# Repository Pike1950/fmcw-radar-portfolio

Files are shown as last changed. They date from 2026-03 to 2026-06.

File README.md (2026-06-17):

# 24 GHz FMCW Radar Sensor

A personal engineering portfolio project: a short-range 24 GHz FMCW radar sensor spanning an RF front end, a mixed-signal I/Q baseband, and an FPGA digital backend. It began as a baseband redesign of a Texas Tech senior capstone (HOTRODS, Spring 2020) and has grown into a complete radar sensor design, carried out with the discipline of 4+ years of hardware validation at Texas Instruments.

## Project Overview

This project demonstrates RF integration, mixed-signal PCB design, digital hardware design, hardware verification, and system-level engineering, with first-principles documentation explaining every design decision. The completed work is a corrected, first-principles baseband design and its system design document; the active phase is scaling that foundation into a full 24 GHz radar sensor.

## The System

An FMCW (Frequency-Modulated Continuous Wave) radar transmits a frequency chirp, receives the reflection from a target, and mixes it with the current transmit frequency to produce a low-frequency beat signal. The beat frequency is proportional to range; the chirp-to-chirp phase gives Doppler velocity, and a complex (I/Q) baseband resolves the sign of that velocity (approaching versus receding).

The sensor is built around an integrated 24 GHz transceiver MMIC and is partitioned into two boards plus a downstream digital backend:

```
RF FRONT-END MODULE                       I/Q BASEBAND BOARD                    DIGITAL BACKEND
BGT24MTR11 (24 GHz, 1 TX / 1 RX)          per channel:                          range-Doppler FFT
 on-chip VCO, PA, LNA, I/Q mixers   I,Q   VGA -> anti-alias -> 18-bit SAR ADC    (FPGA / MCU) -> host
 TX/RX antennas, chirp ramp,        --->  I and Q sampled simultaneously
 first gain stage                  (zero  SPI control of the MMIC
                                     IF)
```

The two boards meet at a low-frequency analog I/Q interface, not a 24 GHz one, because the MMIC downconverts on-chip. That seam is what makes the split practical: the costly, iteration-prone 24 GHz RF and antennas stay on a small module, while the baseband stays on inexpensive FR4 and can be brought up and validated on its own.

## Evolution: Rev A to Rev B to Rev C

- **Rev A (2020).** 5.8 GHz, 3 RX channels, 182 components, Eagle, a single flat sheet. Built as the Texas Tech senior capstone; non-functional. The headline defect was a 10 kHz chirp rate that produced only about 5 ADC samples per ramp, far too few for FFT range extraction.
- **Rev B (current).** Began as a scaled, corrected 5.8 GHz baseband (one channel, KiCad 9, a modern signal chain, DFT-first methodology), captured as schematic plus a first-principles system design document. Rather than fabricate that band, Rev B is now redefined as the **24 GHz I/Q radar**: the band moves to 24 GHz, the project adopts the BGT24MTR11 (so it now owns the RF front end, not just the baseband), the baseband goes complex I/Q, and the sensor splits into an RF module and a baseband board. The baseband modernization below carries forward intact.
- **Rev C.** Additional receive channels for angle estimation, the original trilateration goal, on a proven single-channel Rev B.

### Baseband modernization (carried forward from the 5.8 GHz Rev B)

These corrections to the capstone baseband are band-agnostic and carry directly into the 24 GHz I/Q design.

| Aspect | Rev A (2020) | Rev B baseband (carried forward) |
| --- | --- | --- |
| EDA | Eagle 9.5, flat single sheet | KiCad 9, hierarchical |
| VGA | LT6230 + MCP4017 I²C digital pot | PGA113 (SPI, internal gain resistors) |
| ADC | ADS1174 (16-bit, 64-pin QFP, solder bridges) | ADS8881 (18-bit, 10-pin VSSOP) |
| SE to Diff | LTC6242 (improvised, no VOCM) | THS4531A (true FDA with VOCM) |
| Power | Single 3.3 V rail | 3V3A / 3V3D split via ferrite bead |
| Reference | Resistor divider | REF5025 (2.500 V, 0.05%, 3 µVpp) |
| DFT | None | J_DFT header, 17 TPs, 5 MMCX, 6 isolation resistors |

On top of this, the 24 GHz move adds an integrated-MMIC RF front end, a complex I/Q baseband (the chain above duplicated for I and Q with simultaneous sampling), and the two-board partition.

## Key Documents

| Document | Description |
| --- | --- |
| [System Design Document](https://pike1950.github.io/fmcw-radar-portfolio/docs/system-design/System_Design_Document_RevB.html) | The 24 GHz radar system SDD, restyled to the PMVB module-doc schema with PHYSICS / DECISION / TRADEOFF / RISK reasoning callouts. Covers the two-board architecture, the carry-over analog design (power, references, gain, anti-alias filter, DFT), the FMCW principles, and an open decision register tracking the remaining 24 GHz choices. |

## Technical Highlights

### Analog and mixed-signal design

- **Supply splitting via ferrite bead.** BLM18PG221SN1D (220 Ω at 100 MHz) isolates analog from digital supply noise on a single continuous ground plane, with first-principles impedance analysis.
- **Paired decoupling capacitors.** Matched cap pairs (for example 10 µF + 100 nF) with different self-resonant frequencies for low impedance across a wide band, placed per a derived trace-inductance budget.
- **DFT-first methodology.** Test points, MMCX probes, and isolation resistors designed before the signal chain, now applied per channel for I and Q.

### System-level analysis

- **Chirp-rate correction.** Identified the Rev A parameter mismatch (about 5 samples per ramp) and derived the corrected chirp plan from first principles (sample-count-per-ramp to FFT resolution). The analysis is carrier-independent and re-derives the 24 GHz filter and ADC plan.
- **Band move to 24 GHz with complex I/Q.** Moving from 5.8 GHz to the 24 GHz ISM band raises range resolution from about 5 m to about 0.6 m and brings the RF front end into scope through an integrated MMIC. Complex I/Q sampling adds sign-of-velocity discrimination.
- **Designed for validation.** The board is designed for standalone bring-up and characterization on a homebrew SCPI instrument platform (see Related Repositories).

### Digital backend (planned)

SystemVerilog modules targeting the Gowin GW5A (Tang Primer 25K): SPI masters for the ADS8881 and the MMIC, a chirp ramp / DDS generator, a configurable FIR, and a deterministic timing controller, all verified with self-checking Verilator testbenches. See `digital/spi-controller/`.

## Related Repositories

| Repository | Description | Status |
| --- | --- | --- |
| [32-bit RISC Pipelined Processor](https://github.com/Pike1950/BradW_ECE4375_RISC_Pipeline) | 4-stage pipelined CPU refactored from Verilog to SystemVerilog. Shares the Verilator-clean SystemVerilog methodology used for this radar's digital backend. | SV conversion complete, synthesis next |
| [Poor Man's Validation Bench](https://github.com/Pike1950/poor-mans-validation-bench) | Modular SCPI + MCP instrument platform: Raspberry Pi 5 orchestration, Pico 2W USB-TMC modules, tiered FPGA. The bring-up and characterization platform for this radar. | Phase 0 complete; Module 1E (AWG) in build |

## Tools and Technologies

- **EDA:** KiCad 9. RF module on a controlled high-frequency stackup; baseband on FR4.
- **Simulation:** LTspice (analog), Verilator (digital), GTKWave (waveforms).
- **HDL:** SystemVerilog (digital backend, verification).
- **FPGA target:** Gowin GW5A (Sipeed Tang Primer 25K) for the digital backend.
- **Documentation:** Markdown rendered to HTML via Pandoc, PMVB-schema design docs with first-principles reasoning callouts.
- **Test automation:** PyVISA, integrating with the Poor Man's Validation Bench.

## Background

This project is one of four interconnected portfolio tracks:

1. **FMCW Radar Sensor** (this repo). RF integration plus mixed-signal PCB plus digital, with first-principles documentation and DFT-first methodology.
2. **Hardware Validation.** 4+ years at Texas Instruments (gate-driver characterization, automated test with LabVIEW / TestStand / PXI, DUT board design in Altium).
3. **Digital Design.** A pipelined RISC processor in SystemVerilog.
4. **Test Infrastructure.** The Poor Man's Validation Bench, a SCPI + MCP instrument platform.

The radar connects all four: a mixed-signal and RF sensor (track 1), designed with validation-engineer discipline (track 2), with an FPGA backend (track 3) characterized on the homebrew bench (track 4).

## Status

- **5.8 GHz baseband foundation (complete).** First-principles system design document and schematic capture of the corrected single-channel baseband. Established the methodology, the analog signal chain, and the DFT infrastructure that all carry forward.
- **24 GHz radar system design (in progress).**
  - System SDD reframed to the radar scope and the PMVB schema.
  - D1 resolved: BGT24MTR11 (1 TX / 1 RX), two-board partition (RF Front-End Module plus I/Q Baseband Board).
  - Open: antenna and RF stackup, ADC arrangement, ramp generation, chirp plan, and digital backend (tracked in the SDD decision register).
- **Next.** RF Front-End Module and I/Q Baseband Board schematics; digital backend RTL; bring-up and characterization on the Poor Man's Validation Bench.

## License

A personal engineering portfolio project. The FMCW radar originated as a Texas Tech senior capstone (HOTRODS, Spring 2020). The Rev B redesign, the 24 GHz radar system design, documentation, and all digital design work are by Bradley Ward.

## Contact

Bradley Ward, bradw858@gmail.com, [LinkedIn](https://linkedin.com/in/bradley-ward-49087766/)

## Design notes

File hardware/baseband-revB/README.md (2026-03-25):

# Baseband Rev B — KiCad 9 Schematic

## Overview

Single-channel FMCW radar baseband signal conditioning path. 4-sheet hierarchical schematic, 90 components, 0 ERC errors.

## Sheets

| Sheet | File | Function | Components |
|---|---|---|---|
| Root | `Baseband PCB.kicad_sch` | Top-level hierarchy with sheet instances | — |
| A | `Baseband_Power_Refs.kicad_sch` | Power (TPS7A2033 LDO, 3V3A/3V3D split), References (REF5025, OPA320 VCM buffer) | 29 |
| B | `Baseband_IF_Input_Protection_Bias.kicad_sch` | SMA input, ESD protection (TPD1E10B06), AC coupling, DC bias to VCM | 7 |
| C | `Baseband_PGA_AntiAlias.kicad_sch` | PGA113 (1–200× gain), 4th-order Sallen-Key Butterworth LP at 15 kHz (LTC6242) | 19 |
| D | `Baseband_FDA_Driver_ADC_SPI_Interface.kicad_sch` | THS4531A FDA, ADS8881 18-bit SAR ADC, J_DFT header, SPI interface | 35 |

## Key Design Decisions

See [Design Rationale](../../docs/design-rationale/RevB_Design_Rationale.html) for first-principles analysis of every component choice.

## Status

- [x] Schematic complete
- [x] ERC clean (0 errors, 0 warnings)
- [ ] Layout in progress

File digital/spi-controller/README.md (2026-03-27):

# SPI Controller — SystemVerilog

## Overview

A SystemVerilog SPI master controller designed to interface with the FMCW radar baseband's ADS8881 ADC and PGA113 programmable gain amplifier. This module bridges the analog baseband project with the digital verification track, demonstrating the full V-model from specification through bench validation.

## Status

**Planned** — RTL design and verification are Phase 4 of the project roadmap.

## Target Specifications

### ADS8881 SPI Interface
- CPOL=0, CPHA=1 (SPI Mode 1)
- SCLK: up to 70 MHz
- 18-bit data, MSB first
- CONVST pulse initiates conversion (600 ns conversion time)
- Data clocked out on SCLK falling edge

### PGA113 SPI Interface
- CPOL=0, CPHA=0 (SPI Mode 0)
- 16-bit command word (8-bit register address + 8-bit gain code)
- Separate chip select from ADC

## Planned Architecture

```
                    SPI Controller (Top)
    ┌─────────────────────────────────────────────┐
    │  ┌────────────┐     ┌────────────┐          │
    │  │ ADC SPI    │     │ PGA SPI    │          │
    │  │ Master     │     │ Master     │          │
    │  │ (Mode 1)   │     │ (Mode 0)   │          │
    │  └──────┬─────┘     └──────┬─────┘          │
    │         │                  │                 │
    │  ┌──────▼──────────────────▼─────┐          │
    │  │        Timing Controller      │          │
    │  │  (CONVST generation, gain     │          │
    │  │   scheduling, sample clock)   │          │
    │  └───────────────────────────────┘          │
    │                                             │
    │  ┌───────────────────────────────┐          │
    │  │     Data Output Interface     │──→ UART  │
    │  │  (FIFO, framing, streaming)   │          │
    │  └───────────────────────────────┘          │
    └─────────────────────────────────────────────┘
```

## Verification Plan

- Constrained-random testbench with self-checking scoreboard
- Timing verification against ADS8881 datasheet specifications
- PGA gain code verification against PGA113 register map
- Coverage targets: all gain settings, all timing corner cases

## FPGA Targets

- **Gowin GW5A** (Sipeed Tang Primer 25K, ~$35, in hand) — 23,040 LUT4, 1008Kb BSRAM, 3 PMOD ports. Primary target for the radar digital backend. Gowin EDA + open-source Yosys/Apicula toolchain.
- **Gowin GW5AST-138** (Sipeed Tang Mega 138K Pro, ~$200) — 138K LUT4, PCIe 3.0 x4, dual SFP+. Phase 2 target for expanded digital backend and high-speed interface work.

## Toolchain

- **Simulation:** Verilator + GTKWave (WSL2 or native Linux)
- **Synthesis:** Yosys (iCE40) or Gowin EDA (GW1NR-9)
- **Place & Route:** nextpnr (iCE40) or Gowin EDA

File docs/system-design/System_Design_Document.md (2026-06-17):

# 24 GHz FMCW Radar System Design Document

## Rev B: 24 GHz I/Q

**Version:** 0.8
**Project:** FMCW Radar Portfolio (`fmcw-radar-portfolio`)
**Revision:** Rev B (24 GHz I/Q)
**Status:** In Design
**Engineer:** Bradley Ward
**Scope:** A complete 24 GHz FMCW radar sensor, partitioned into two boards: an **RF Front-End Module** (BGT24MTR11, 24 GHz antennas, chirp ramp, first gain stage) and an **I/Q Baseband Board** (gain, anti-alias filtering, dual simultaneous-sampling ADC, digital interface). The digital backend that runs the range-Doppler FFT is downstream of both.

---

## Document Conventions

This document follows the PMVB module-doc section schema. The reasoning style from the original FMCW SDD is preserved: load-bearing design choices are called out with one of four tags so the "why" is explicit and auditable.

<div class="callout callout-blue"><strong><span class="tag tag-physics">PHYSICS</span> First-principles derivation or physical reasoning.</strong></div>
<div class="callout callout-teal"><strong><span class="tag tag-decision">DECISION</span> A specific design choice with its rationale.</strong></div>
<div class="callout"><strong><span class="tag tag-tradeoff">TRADEOFF</span> What was gained versus what was given up.</strong></div>
<div class="callout callout-red"><strong><span class="tag tag-risk">RISK</span> A known limitation or sensitivity requiring attention.</strong></div>

A fifth marker is specific to this revision. Because the 24 GHz design is mid-definition, blocks that depend on an unresolved decision are flagged and cross-referenced to the decision register in section 10:

<div class="pending"><strong>PENDING (Dx):</strong> content blocked on an open decision; see section 10.</div>

Per the PMVB rule, the body describes what is used. Where a 24-GHz choice is not yet locked, the section states what carries over from the 5.8 GHz design, what must change, and which decision gates it, rather than guessing values that will move.

---

## Table of Contents

- [1. Theory of Operation](#theory-of-operation)
  - [1.1 What the system does](#what-the-system-does)
  - [1.2 Signal chain](#signal-chain)
  - [1.3 Methodology: work backward from the ADC](#methodology-work-backward-from-the-adc)
  - [1.4 The coupled parameter chain](#the-coupled-parameter-chain)
  - [1.5 The baseband is set by the chirp plan, not the carrier](#the-baseband-is-set-by-the-chirp-plan-not-the-carrier)
- [2. Functional Block Diagram](#functional-block-diagram)
- [3. Schematic Notes](#schematic-notes)
  - [3.0 RF Front-End Module](#rf-front-end-module)
  - [3.1 Sheet A: Power and References](#sheet-a-power-and-references)
  - [3.2 Sheet B: I/Q Input from the MMIC](#sheet-b-iq-input-from-the-mmic)
  - [3.3 Sheet C: Gain and Anti-Alias Filter](#sheet-c-gain-and-anti-alias-filter)
  - [3.4 Sheet D: I/Q Digitization](#sheet-d-iq-digitization)
  - [3.5 DFT Infrastructure](#dft-infrastructure)
- [4. Pin Assignments](#pin-assignments)
- [5. Specifications](#specifications)
  - [5.1 Governing equations](#governing-equations)
  - [5.2 Key relationships, visualized](#key-relationships-visualized)
- [6. Sample Applications](#sample-applications)
- [7. Bill of Materials](#bill-of-materials)
- [8. Calibration Procedure](#calibration-procedure)
- [9. Layout Design Rationale](#layout-design-rationale)
- [10. Open Decisions and Known Issues](#open-decisions-and-known-issues)
- [11. References](#references)

---

## 1. Theory of Operation

### 1.1 What the system does

This is a complete short-range 24 GHz FMCW radar sensor. A transceiver MMIC transmits a frequency chirp, receives the reflection, and downconverts it on-chip to a complex baseband beat signal; the baseband then conditions and digitizes that signal into complex samples for a downstream range-Doppler FFT.

The sensor is partitioned into two boards (decision D1, section 10):

- **RF Front-End Module.** The Infineon BGT24MTR11 (1 TX / 1 RX) integrated transceiver, its 24 GHz TX and RX antennas, the chirp ramp source, and a first gain stage. The MMIC contains the VCO, PA, LNA, and quadrature mixers and presents differential in-phase (I) and quadrature (Q) beat signals at zero IF.
- **I/Q Baseband Board.** Per-channel gain and anti-alias filtering, simultaneous 18-bit sampling of I and Q, MMIC configuration over SPI, and the digital interface to the backend.

The two boards meet at a low-frequency analog I/Q interface, not a 24 GHz interface, because the MMIC has already downconverted on-chip. That is what makes the split practical (section 10, D1).

The radar is a signal-acquisition path, not a signal processor: it transforms microvolt-to-millivolt beat signals into clean complex samples, and range and velocity extraction happen downstream in the FFT engine.

<div class="callout callout-teal"><strong><span class="tag tag-decision">DECISION</span> 24 GHz integrated MMIC, two-board partition</strong>
<p>The 5.8 GHz Rev B was baseband-only and treated the RF front end (a discrete free-running VCO, mixers, and LNA) as external. At 24 GHz the project adopts the BGT24MTR11, which collapses that discrete RF chain into a single MMIC, so the RF front end is now part of the design. The sensor is split into an RF Front-End Module and an I/Q Baseband Board because the inter-board seam is low-frequency analog I/Q: that keeps the costly 24 GHz material and the iteration-prone RF isolated to a small board while the baseband stays on cheap FR4 and can be validated standalone. The complex I/Q output is also what enables sign-of-velocity discrimination (sections 1.5 and 3.4).</p></div>

### 1.2 Signal chain

Locked blocks are in plain text; blocks whose implementation depends on an open decision are flagged.

```
RF FRONT-END MODULE
  24 GHz MMIC (on-chip VCO, PA, LNA, I/Q mixers); TX and RX via 24 GHz antennas
  I, Q (zero IF) -> first gain stage -> [ I/Q interface connector ]
  chirp ramp -> MMIC VCO tune (kept local to this board)     (DAC ramp, calibrated)

I/Q BASEBAND BOARD
  [ I/Q interface connector ] -> per channel: VGA -> anti-alias filter -> SAR ADC
     I and Q sampled simultaneously to preserve complex phase
  -> digital backend: Tang Primer 25K FPGA (range-Doppler FFT) -> host
  MMIC configuration + control over SPI (routed across the connector)
```

The two conditioning chains (I and Q) are nominally identical. Channel-to-channel gain and phase match is a first-class concern: I/Q imbalance maps directly to image-frequency leakage in the complex spectrum and corrupts the sign of the measured velocity.

### 1.3 Methodology: work backward from the ADC

This methodology carries over from the 5.8 GHz design unchanged, because it is independent of carrier frequency and of real-versus-complex sampling. Every analog decision is anchored to what the ADC needs to see.

<div class="callout callout-blue"><strong><span class="tag tag-physics">PHYSICS</span> The ADC defines the budget</strong>
<p>The ADS8881 digitizes a differential input against a 2.500 V reference (REF5025). One LSB at 18 bits over the differential full scale is V<sub>REF</sub> &times; 2 / 2<sup>18</sup> = 5.000 V / 262,144 &approx; 19 &micro;V. Every upstream stage exists to deliver a clean signal into that window: the VGA fills the ADC range regardless of target distance, the anti-alias filter keeps out-of-band energy from folding in, and the reference and bias networks must hold stable to a small fraction of an LSB or they waste resolution. Noise or offset referred to the input is only meaningful relative to that ~19 &micro;V step.</p></div>

### 1.4 The coupled parameter chain

The chirp timing, the sample rate, and the FFT size are not independent. They are bound by one relation that Rev A violated and Rev B respects.

<div class="callout callout-blue"><strong><span class="tag tag-physics">PHYSICS</span> The three coupled parameters</strong>
<p>f<sub>s</sub> &times; T<sub>sweep</sub> = N<sub>samples</sub>, and N<sub>samples</sub> must be at least N<sub>FFT</sub> for useful frequency resolution.</p>
<p>Rev A set T<sub>sweep</sub> = 50 &micro;s without checking: at 100 kS/s that is only 5 samples per ramp, and a 5-point FFT has no resolution. The corrected design sets T<sub>sweep</sub> in the millisecond range so that f<sub>s</sub> &times; T<sub>sweep</sub> yields several hundred samples per ramp, enough for a 512-point FFT. The ADC sample rate did not cause the Rev A failure; the chirp rate did.</p></div>

<div class="callout callout-teal"><strong><span class="tag tag-decision">DECISION</span> Chirp plan (D6)</strong>
<p>Sweep 250 MHz over a 1 ms chirp (slope 250 GHz/s), 50 m design range, sampled at 256 kSPS for 256 samples per chirp and a 256-point range FFT (~83 range bins of 0.6 m). 128 chirps per frame give a 128 ms frame (~8 frames/s), ~5 cm/s velocity resolution, and ±3.1 m/s unambiguous velocity. The max beat at 50 m is 83 kHz, well inside the 128 kHz Nyquist, leaving the anti-alias filter an 83-to-128 kHz transition band. More range is paid for with sample rate (the ADS8881 reaches 1 MSPS), not chirp time, so velocity is unaffected.</p></div>

### 1.5 The baseband is set by the chirp plan, not the carrier

This is the point that makes the band move tractable: moving from 5.8 GHz to 24 GHz does not, by itself, change the baseband.

<div class="callout callout-blue"><strong><span class="tag tag-physics">PHYSICS</span> Beat frequency depends on slope and range, not carrier</strong>
<p>For a target at range R, the beat frequency is f<sub>beat</sub> = 2&middot;R&middot;S / c, where S is the chirp slope (sweep bandwidth / sweep time). The carrier frequency f<sub>0</sub> does not appear. So the anti-alias filter cutoff and the ADC rate are governed by the maximum range beat, set by the chirp plan, and are re-derived with the same analysis used at 5.8 GHz.</p>
<p>Range resolution is set by usable sweep bandwidth: &Delta;R = c / (2B). Across the 24 GHz ISM band (~250 MHz usable) the floor is about 0.6 m, roughly an 8&times; improvement over the 30 MHz / 5.0 m of the 5.8 GHz §15.245 mode, and a hard limit independent of the ADC.</p></div>

<div class="callout callout-blue"><strong><span class="tag tag-physics">PHYSICS</span> What the carrier does change: Doppler</strong>
<p>Doppler shift scales with carrier: f<sub>D</sub> = 2&middot;v&middot;f<sub>0</sub> / c. At 24 GHz the Doppler is about 4&times; that at 5.8 GHz for the same velocity. Doppler is resolved in the slow-time (chirp-to-chirp) FFT and sets velocity-axis scaling and maximum unambiguous velocity; it does not drive the fast-time anti-alias filter, which remains governed by the range beat.</p></div>

<div class="callout callout-teal"><strong><span class="tag tag-decision">DECISION</span> Complex I/Q resolves the sign of velocity</strong>
<p>A single real beat channel cannot tell an approaching target from a receding one; both fold to the same positive beat frequency. Sampling I and Q gives a complex baseband whose FFT is two-sided, so positive and negative Doppler are distinct. This is the architectural reason the board doubles to two channels (section 3.4) and the reason simultaneous sampling and I/Q match matter.</p></div>

---

## 2. Functional Block Diagram

The system and sheet-level block diagrams live in `docs/block-diagrams/` (`block_diagram_system.svg`, `block_diagram_sheet_a.svg`, `block_diagram_sheets_bcd.svg`).

The existing diagrams show the 5.8 GHz single real chain (one mixer input, one PGA, one filter, one FDA, one ADC). They are redrawn to show the two-board partition: the BGT24MTR11 with its antennas and first gain stage on the RF Front-End Module, the differential I and Q crossing the interface connector, and the two parallel conditioning chains into a simultaneous-sampling ADC stage on the I/Q Baseband Board.

---

## 3. Schematic Notes

The design spans two boards. The notes below explain the intent behind each block; the full schematics live in the KiCad projects, and detailed per-board design documents (RF Front-End Module, I/Q Baseband Board) will sit under this system SDD as each board matures, mirroring the PMVB per-module docs. Section 3.0 summarizes the RF Front-End Module; sections 3.1 to 3.5 cover the I/Q Baseband Board, where Sheet A (power and references) and the DFT infrastructure carry over from the 5.8 GHz design and Sheets B, C, and D are reworked for the MMIC I/Q interface and the dual-channel architecture.

### 3.0 RF Front-End Module

The RF Front-End Module carries the BGT24MTR11 transceiver, its 24 GHz TX and RX antennas, the chirp ramp source, a first gain stage on each of the I and Q outputs, and the connector to the baseband board.

<div class="callout callout-teal"><strong><span class="tag tag-decision">DECISION</span> The first gain stage lives on the RF module</strong>
<p>The I and Q signals leaving the MMIC are low-level (microvolt to millivolt) and have to cross a board-to-board connector. A first gain stage on the RF module amplifies them before the crossing, so the inter-board interface carries a larger, lower-impedance signal and is far less vulnerable to pickup. The remaining gain and all of the filtering live on the baseband board.</p></div>

<div class="callout callout-teal"><strong><span class="tag tag-decision">DECISION</span> External patch array on 4-layer RO4350B (D2)</strong>
<p>The RF module uses external PCB patch antennas (a small patch array), microstrip-fed from the BGT24MTR11, plus a build-option 2.92 mm connector launch (DNP) so an external 24 GHz antenna can drive first bring-up. The stackup is 4-layer RO4350B (L1 RF and antenna, L2 solid ground reference, L3 power, L4 control), fabricated at PCBWay, which runs 4-layer Rogers. RO4350B sits just above its sweet spot at 24 GHz, giving up a little patch efficiency versus RO3003, which is held as a later upgrade. ENIG finish for the fine-pitch MMIC and the patches.</p></div>

<div class="callout callout-teal"><strong><span class="tag tag-decision">DECISION</span> DAC-driven chirp ramp with calibration (D5)</strong>
<p>The VCO tune voltage is generated open-loop by a DAC and pre-distorted from a measured frequency-versus-voltage curve, rather than closed-loop with an FMCW ramp PLL. Over the ~250 MHz sweep at 24 GHz the fractional bandwidth is about 1%, the same regime in which the original 5.8 GHz design ran its VCO, so the residual nonlinearity is modest and a calibrated open-loop ramp is adequate. The ramp source stays local to the RF module so the tune line is short. The accepted cost is open-loop drift with temperature and the calibration table to maintain; an ADF4159-class ramp PLL is the upgrade path if bench measurement shows linearity is limiting range accuracy.</p></div>

### 3.1 Sheet A: Power and References

Sheet A is band-agnostic and carries over essentially intact, with one change: the common-mode and reference nets now fan out to two channels instead of one. The architecture is a single 5 V input, an on-board 3.3 V LDO, an analog/digital supply split via ferrite bead, a precision 2.500 V reference, and a buffered mid-supply common-mode rail.

<div class="callout callout-teal"><strong><span class="tag tag-decision">DECISION</span> Analog/digital split via ferrite bead, single ground plane</strong>
<p>The 3V3A and 3V3D rails are separated by a BLM18PG221SN1D ferrite bead (220 &Omega; at 100 MHz, under 1 &Omega; DC). It passes DC cleanly to the analog rail while presenting high impedance to the digital switching spectrum, giving over 40 dB of attenuation to SPI-edge noise. The ground stays a single continuous plane; isolation is done on the supply, not by splitting the return (see section 9.3).</p></div>

<div class="callout callout-blue"><strong><span class="tag tag-physics">PHYSICS</span> Why V<sub>CM</sub> = V<sub>DD</sub>/2 = 1.650 V</strong>
<p>All active parts run from a single 3.3 V supply with no negative rail, so an AC signal must be biased to the midpoint to maximize swing before clipping. At V<sub>CM</sub> = 1.650 V the signal gets symmetric &plusmn;1.65 V headroom (less op-amp saturation, ~100&ndash;200 mV per rail). This common-mode voltage appears everywhere: it biases the I/Q inputs, sets the PGA reference, and drives each FDA's VOCM pin. A single buffered, low-impedance source (an OPA320 on Sheet A) feeds all stages so they share one common mode; any mismatch becomes a DC offset that wastes ADC range. With two channels, the same buffered V<sub>CM</sub> and V<sub>REF</sub> nets fan out to both I and Q.</p></div>

<div class="callout callout-blue"><strong><span class="tag tag-physics">PHYSICS</span> Reference error is gain error</strong>
<p>REF5025 (2.500 V, 0.05%, 3 &micro;V<sub>pp</sub> noise) sets the ADC full scale. Any error in V<sub>REF</sub> maps directly to a gain error on every reading: gain error = &Delta;V<sub>REF</sub> / V<sub>REF,nom</sub>. The reference therefore gets a paired-capacitor decoupling network (10 &micro;F bulk + 100 nF high-frequency, different self-resonant frequencies) at the ADC reference pin, as the ADS8881 datasheet recommends.</p></div>

<div class="callout callout-teal"><strong><span class="tag tag-decision">DECISION</span> Decoupling placement is a derived budget, not a guideline</strong>
<p>Trace inductance is ~1 nH/mm. The placement distance for each bypass capacitor follows from the frequency it must serve and the acceptable trace impedance: the higher the frequency, the shorter the trace. The design's rules (100 nF within 2 mm, 1 &micro;F within 5 mm, 10 &micro;F within 10 mm) are the quantitative result of that inductance-versus-impedance analysis, not copied from a reference design. This carries over unchanged.</p></div>

### 3.2 Sheet B: I/Q Input from the MMIC

This is the most-changed sheet. The 5.8 GHz Sheet B was a single-ended, AC-coupled input: an SMA from a discrete mixer, a series current-limit resistor, an ESD diode, a 100 nF C0G capacitor to strip the mixer's undefined DC, and a 47 kΩ bias to V<sub>CM</sub> (high-pass corner ~34 Hz). For a 24 GHz zero-IF I/Q front end that topology is largely replaced.

<div class="pending"><strong>Input interface (D1 resolved):</strong> The BGT24MTR11 presents differential I and Q at zero IF. The baseband-board input interfaces to two differential pairs arriving over the interconnect from the RF module's first gain stage, not a single-ended SMA. The exact termination, common-mode handling, and ESD network follow the BGT24MTR11 I/Q output specification.</div>

<div class="callout callout-red"><strong><span class="tag tag-risk">RISK</span> Zero-IF DC must not be blocked</strong>
<p>The old Sheet B AC-coupled specifically to remove the mixer's undefined DC bias. At zero IF the beat band extends down to DC, so a stationary or slow-moving target sits near DC. The Rev B input cannot high-pass the way the 5.8 GHz design did. DC offset is handled instead (per-channel calibration or a servo), and 1/f (flicker) noise now sits in-band and must be budgeted. This is the single biggest conceptual change from the old input stage.</p></div>

<div class="callout callout-teal"><strong><span class="tag tag-decision">DECISION</span> Keep ESD and current-limiting, adapted to differential</strong>
<p>The connector/interface ESD protection (TPD1E10B06 class) and the per-line series current-limit concept carry over, applied to each leg of the differential I and Q pairs rather than a single-ended line.</p></div>

### 3.3 Sheet C: Gain and Anti-Alias Filter

The gain and filter method carries over; the component values re-derive from the 24 GHz chirp plan (D6), and the whole chain duplicates for I and Q.

<div class="callout callout-blue"><strong><span class="tag tag-physics">PHYSICS</span> Variable gain follows the R<sup>&minus;4</sup> range law</strong>
<p>Received power varies as R<sup>&minus;4</sup> (the radar range equation): a target at 10 m returns 10,000&times; the power of the same target at 100 m, about 40 dB, and a 100-to-1 span is roughly 80 dB, which approaches the ~84 dB an 18-bit SAR can usefully cover and is exceeded for wider spans. Without variable gain the ADC would clip on near targets or bury far ones in the noise. An SPI-controlled differential VGA per channel fills the ADC window for each range regime. (The Rev B PGA113 was a single-ended part; the differential I/Q here keeps the gain stage differential, so the adaptive-gain concept and the SPI control carry forward, but the part changes.)</p></div>

<div class="callout callout-teal"><strong><span class="tag tag-decision">DECISION</span> Anti-alias before sampling, cutoff set by Nyquist not by the chirp</strong>
<p>A 4th-order Sallen-Key Butterworth low-pass sits before each ADC. Its cutoff is set by f<sub>s</sub>/2 and the signal band, not by the chirp rate. Whether the chirp is fast or slow, energy above Nyquist must be kept from folding into the band. The topology and the singly-terminated design method carry over from the 5.8 GHz Sheet C. With the chirp plan set (D6: 256 kSPS, 83 kHz max beat), the cutoff lands near 100 kHz, inside the 83-to-128 kHz window between the max beat and Nyquist; the L/C/R values follow from a Butterworth synthesis at that cutoff.</p></div>

<div class="callout"><strong><span class="tag tag-tradeoff">TRADEOFF</span> Duplicating for Q buys complex sampling at the cost of match</strong>
<p>Adding a second identical gain-plus-filter chain for Q is what enables sign-of-velocity, but it introduces channel mismatch. Gain and phase match between the I and Q chains must be held through matched components and symmetric layout, or image rejection in the complex FFT degrades.</p></div>

<div class="callout callout-teal"><strong><span class="tag tag-decision">DECISION</span> Adaptive differential gain per channel (D4)</strong>
<p>Each channel uses an SPI-controlled differential VGA rather than a fixed-gain stage, so the receiver fills the 18-bit ADC across the R<sup>&minus;4</sup> range swing instead of compromising between near-target clipping and far-target SNR. A differential VGA (not the single-ended PGA113) keeps the I/Q path differential through to the ADC; the part is chosen to match the BGT24MTR11 I/Q levels and the ADS8881 input range. I and Q use matched VGAs, with residual gain and phase mismatch calibrated on PMVB.</p></div>

The only open item on this sheet is the component synthesis at that cutoff, which is design work, not a gated decision.

### 3.4 Sheet D: I/Q Digitization

This sheet changes from one ADC to a simultaneous-sampling I/Q pair. The ADS8881 and REF5025 rationale carry over; the count doubles and the convert is shared.

<div class="callout callout-teal"><strong><span class="tag tag-decision">DECISION</span> Two ADS8881 on a shared CONVST, simultaneous I/Q (D3)</strong>
<p>To preserve the complex phase relationship between I and Q, the two channels are sampled at the same instant. Two ADS8881 18-bit SAR ADCs share one CONVST line so their sample apertures coincide. This reuses the proven Rev B converter, the REF5025 reference, and the existing SPI controller RTL; the one cost, a small inter-channel aperture skew, is negligible at the radar's low beat frequencies and is calibrated out on PMVB. Because the MMIC output is already differential, the THS4531A's old single-ended-to-differential role is revisited: it likely becomes a differential receiver and level-shifter into the ADC rather than an SE-to-Diff converter.</p></div>

<div class="callout callout-blue"><strong><span class="tag tag-physics">PHYSICS</span> SAR, not sigma-delta</strong>
<p>A SAR ADC samples at a discrete, deterministic instant. A sigma-delta averages over its decimation window, which would smear the instantaneous beat frequency and corrupt the range-Doppler FFT. The ADS8881 (18-bit, up to 1 MSPS, run well below its maximum) is the right converter class, and this rationale is unchanged from the 5.8 GHz design.</p></div>

<div class="callout callout-teal"><strong><span class="tag tag-decision">DECISION</span> Tang Primer 25K FPGA backend (D7)</strong>
<p>A Gowin GW5A (Tang Primer 25K) ingests both ADC streams over SPI and runs the range-Doppler FFT, reusing the SPI controller RTL and the Verilator-clean SystemVerilog methodology shared with the RISC CPU project. The ~9 Mbps data rate is light for the part; the FPGA is chosen over an MCU for the digital-design showcase and the RTL reuse, with a board dedicated per radar (additional Tang Primers planned rather than time-sharing the PMVB unit).</p></div>

### 3.5 DFT Infrastructure

Design-for-test is a first-class requirement and carries over, now per channel. The 5.8 GHz board used a J_DFT header, 17 test points, 5 MMCX probe connectors, and six 10 kΩ isolation resistors on the analog monitor nets.

<div class="callout callout-blue"><strong><span class="tag tag-physics">PHYSICS</span> An isolation resistor plus a probe is a harmless low-pass</strong>
<p>A 10 kΩ isolation resistor with a ~15 pF scope-probe tip forms a low-pass at f = 1/(2&pi; &times; 10k &times; 15p) &approx; 1 MHz, well above the beat band, so the probe point never meaningfully loads the chain. The resistors are always populated; they protect the signal chain even when the header is unconnected.</p></div>

<div class="callout callout-teal"><strong><span class="tag tag-decision">DECISION</span> Per-channel observability</strong>
<p>With two chains, the monitor set (VGA output, filter output, ADC differential inputs, FDA outputs) is provided for both I and Q, so each path is independently observable. Bring-up and characterization run on the PMVB instrument platform rather than commercial bench gear.</p></div>

---

## 4. Pin Assignments

With the backend fixed as the Tang Primer 25K (D7), the interface is defined in kind and the detailed pin map is now a design task. The two ADS8881 and the MMIC sit on a shared SPI bus (shared SCLK and SDI, per-device chip-select), the ramp DAC drives the VCO tune, and the FPGA generates CONVST and the chirp timing. The J_DFT pinout concept carries over, extended for the second channel and the MMIC control interface.

---

## 5. Specifications

This section locks the sensor's numbers, traces each to the relationship it comes from, and plots the three that dominate performance. The values here are carried in parity with the downstream summary tables as they lock.

| Parameter | Value | Status |
|---|---|---|
| Carrier band | 24 GHz ISM, 24.0&ndash;24.25 GHz (~250 MHz usable) | Locked |
| Range resolution floor | ~0.6 m (&Delta;R = c/2B at 250 MHz) | Locked |
| Baseband | Complex I/Q, two channels, simultaneous sampling | Locked |
| ADC | Two ADS8881 (18-bit SAR), differential, shared CONVST for simultaneous I/Q, 2.500 V REF5025 | Locked |
| Sweep bandwidth / chirp duration / slope | 250 MHz / 1 ms / 250 GHz/s | Locked (D6) |
| Max range (design) | 50 m (sample rate gives headroom; far detection is link-budget-limited) | Locked (D6) |
| Max beat frequency / sample rate | 83 kHz at 50 m / 256 kSPS | Locked (D6) |
| Samples per chirp / range FFT | 256 / 256-point (~83 range bins) | Locked (D6) |
| Chirps per frame / frame rate | 128 / ~8 frames per second | Locked (D6) |
| Velocity resolution / max unambiguous velocity | ~5 cm/s / ±3.1 m/s | Locked (D6) |
| I/Q gain and phase match target | sets image rejection | Design + calibration (matched VGAs) |
| Digital backend | Tang Primer 25K (Gowin GW5A) FPGA, range-Doppler FFT, ~9 Mbps ingest | Locked (D7) |

### 5.1 Governing equations

Each locked value above traces to one relationship: range to the beat frequency, resolution to swept bandwidth, and the velocity pair to chirp and frame timing. The 24 GHz carrier sets only the wavelength, not the resolution, which is why the case for the band move is the bandwidth it opens up rather than the frequency itself.

| Quantity | Equation | This design |
|---|---|---|
| Wavelength | λ = c / f<sub>0</sub> | 12.5 mm at 24 GHz |
| Range resolution | ΔR = c / (2B) | 0.6 m at B = 250 MHz |
| Chirp slope | S = B / T<sub>chirp</sub> | 250 GHz/s |
| Beat frequency | f<sub>beat</sub> = 2·R·S / c | 1.67 kHz/m, so 83 kHz at 50 m |
| Max unambiguous range | R<sub>max</sub> ≈ f<sub>s</sub>·c / (4S) | ~77 m at 256 kSPS (Doppler-reserved; up to ~2&times; with the full complex span) |
| Max unambiguous velocity | v<sub>max</sub> = λ / (4·T<sub>chirp</sub>) | ±3.1 m/s at T<sub>chirp</sub> = 1 ms |
| Velocity resolution | Δv = λ / (2·T<sub>frame</sub>) | ~5 cm/s at T<sub>frame</sub> = 128 ms |

### 5.2 Key relationships, visualized

Three of these relationships set the headline performance.

<figure>
FMCW transmit and receive chirps and the constant beat frequency between them
<figcaption><strong>Figure 5-1.</strong> The FMCW principle. <em>Top:</em> the transmit chirp (slope S = B/T<sub>C</sub>) and its echo from one target, the same chirp delayed by the round-trip time &tau; = 2R/c. Because the echo shares the slope, the transmit-to-echo gap is a constant beat frequency f<sub>beat</sub> = S&middot;&tau; (equivalently 2RS/c). <em>Bottom:</em> that gap is one constant beat tone, switching on when the echo returns; its frequency sets the target's range.</figcaption>
</figure>

<figure>
Beat frequency versus target range with the 50 m design point below the 128 kHz Nyquist ceiling
<figcaption><strong>Figure 5-2.</strong> Beat frequency versus target range at the design slope. The 50 m design point lands at 83 kHz, well under the 128 kHz Nyquist of 256 kSPS sampling; the line reaches Nyquist near 77 m, the unambiguous-range ceiling.</figcaption>
</figure>

<figure>
Range resolution versus sweep bandwidth, 30 MHz versus the 250 MHz design point
<figcaption><strong>Figure 5-3.</strong> Range resolution versus sweep bandwidth, &Delta;R = c/2B. The full 250 MHz ISM band gives 0.6 m, about an 8&times; improvement over the 30 MHz / 5 m of the old 5.8 GHz mode.</figcaption>
</figure>

Read together, the three trace the whole chain: Figure 5-1 is why range becomes a frequency, Figure 5-2 turns that into the sample-rate budget (the 50 m / 83 kHz design point under the 128 kHz Nyquist), and Figure 5-3 is the case for the 24 GHz band, the 250 MHz sweep that takes resolution from 5 m to 0.6 m.

---

## 6. Sample Applications

Outline; the backend is the Tang Primer 25K FPGA (D7), and these recipes detail out as the firmware and RTL come up.

1. **Single moving target.** Transmit a chirp frame, capture I and Q, run the range-Doppler FFT, read the occupied range bin and the sign of the Doppler (approaching versus receding).
2. **Two targets at different ranges.** Demonstrate range separation at the ~0.6 m resolution floor.
3. **Bench characterization on PMVB.** Stimulus and measurement recipe for noise floor, I/Q gain and phase match, and chirp linearity using PMVB Tier 1 / Tier 2 modules.

---

## 7. Bill of Materials

The architecture parts are now fully specified across both boards and the backend. The final BOM with exact passives and part numbers is produced at schematic capture, sourced per the PMVB rule (Mouser &gt; Digi-Key &gt; Microcenter &gt; Amazon).

Carries over: ADS8881 (&times;2, one per I/Q channel), REF5025, THS4531A, OPA320, TPS7A2033 LDO, BLM18PG221SN1D ferrite. Changes: the single-ended PGA113 is replaced by a differential VGA per channel (D4). Adds: the BGT24MTR11 transceiver and its RF-module support, a ramp DAC for the VCO tune (D5), a Tang Primer 25K FPGA backend (D7), and second-channel duplicates of the conditioning chain.

---

## 8. Calibration Procedure

Targets (outline; detailed once the chain and backend lock): I/Q gain match, I/Q phase match (image rejection), per-channel DC offset (the zero-IF concern from section 3.2), chirp linearity, and range accuracy. Each references the SCPI commands the bring-up firmware exposes.

---

## 9. Layout Design Rationale

The layout rationale carries over almost wholesale. The original chapter notes that at a DC-to-tens-of-kHz beat band, transmission-line impedance and wavelength effects are irrelevant; the real layout drivers are confining return current and isolating digital (SPI) noise. Those drivers are unchanged at 24 GHz, because the high-frequency RF is inside the MMIC, not on this board.

- **Stackup (carries over).** 4-layer: L1 signal and components, L2 continuous ground with no splits, L3 power (3V3A pour with a small 3V3D island), L4 secondary signal.
- **Ground plane (carries over).** One continuous unbroken ground; the split-plane approach is rejected on a worked loop-area noise calculation (a split forces a large return loop and tens of LSBs of induced noise; the continuous plane keeps it to a fraction of an LSB).
- **Placement (carries over, duplicated).** Signal-flow zones left to right, bypass placement per the derived budget, FDA-to-ADC pin-to-pin under 5 mm. The analog chain zone is duplicated for the Q path.

<div class="callout callout-teal"><strong><span class="tag tag-decision">DECISION</span> Dual I/Q differential routing</strong>
<p>Two matched differential pairs run into the two ADCs, each length-matched (the original ~0.4 ns skew budget transfers). New for I/Q: inter-pair separation (3W or a guard trace) so the I and Q pairs do not couple, and channel-to-channel layout symmetry so the gain and phase match the design depends on actually holds on the board.</p></div>

---

## 10. Open Decisions and Known Issues

All seven architecture decisions (D1 through D7) are resolved. The register below is the settled record; the next phase is schematic capture, not further architecture decisions.

| # | Decision | Options | Drives | Depends on |
|---|---|---|---|---|
| D1 | MMIC and board split | **RESOLVED:** BGT24MTR11 (1 TX / 1 RX); two boards (RF Front-End Module + I/Q Baseband Board), split at the low-frequency I/Q seam after a first gain stage on the RF module | I/Q interface, RF layout scope, connectors | done |
| D2 | Antenna and RF stackup | **RESOLVED:** external PCB patch array + DNP 2.92 mm connector launch; 4-layer RO4350B at PCBWay (RO3003 held as a later efficiency upgrade), ENIG finish | RF layout, stackup, cost | done |
| D3 | ADC arrangement | **RESOLVED:** two synchronized ADS8881 (18-bit SAR) on a shared CONVST; reuses the proven part, REF5025, and SPI RTL | I/Q phase fidelity, BOM, layout | done |
| D4 | Front-end gain | **RESOLVED:** adaptive gain via an SPI-controlled differential VGA per channel (replaces the single-ended PGA113); matched I/Q, residual calibrated on PMVB | gain match, dynamic range | done |
| D5 | Ramp generation | **RESOLVED:** DAC-driven VCO tune with calibration (open-loop, adequate at ~1% fractional BW); ADF4159-class ramp PLL noted as the upgrade if linearity limits range | chirp linearity, parts, firmware | done |
| D6 | Chirp plan | **RESOLVED:** 250 MHz / 1 ms (250 GHz/s), 50 m, 256 kSPS, 256-pt FFT, 128 chirps/frame; 0.6 m range res, ±3.1 m/s, ~5 cm/s, ~8 fps | filter cutoff, ADC rate, range/velocity | done |
| D7 | Digital backend | **RESOLVED:** Tang Primer 25K (Gowin GW5A) FPGA running the range-Doppler FFT, reusing the SPI controller RTL and SystemVerilog methodology; dedicated board per radar (more Tang Primers planned) | throughput, FPGA acquisition | done |

**Known issues / future work.** Rev C adds receive channels for angle estimation (the original 1 TX / 3 RX trilateration goal) on a proven single-channel Rev B front end.

<div class="callout callout-red"><strong><span class="tag tag-risk">RISK</span> The 5.8 GHz design already flagged the chirp-linearity path</strong>
<p>The original SDD noted that the free-running HMC431LP4E VCO was acceptable only because the 30 MHz mode used ~5% of its tuning range, and that wider sweeps would reveal nonlinearity for which a PLL-based control loop was the recommended upgrade. At 24 GHz over ~250 MHz the fractional bandwidth is again about 1%, so D5 takes the calibrated open-loop DAC ramp, with an ADF4159-class FMCW ramp PLL held as the upgrade if bench measurement shows chirp linearity is limiting range accuracy.</p></div>

---

## 11. References

Carried over from the 5.8 GHz SDD:

- Eric Bogatin, *Signal and Power Integrity, Simplified* (Prentice Hall).
- Henry Ott, *Electromagnetic Compatibility Engineering* (Wiley), Ch. 17&ndash;18.
- TI SLYT499 / SLYT512, grounding in mixed-signal systems.
- TI SLTA055, bypass capacitor selection for high-speed ADCs; Murata capacitor impedance library.
- TI SLOA024B, analysis of the Sallen-Key architecture.
- TI SLOA054, fully differential amplifiers; THS4531A and ADS8881 datasheets.
- Merrill Skolnik, *Introduction to Radar Systems* (McGraw-Hill).

Added for Rev B (24 GHz I/Q):

- Infineon BGT24MTR11 24 GHz transceiver datasheet (front-end candidate, D1).
- Analog Devices ADF4159 FMCW ramp-generating PLL datasheet (ramp candidate, D5).
- FCC rules for the 24 GHz ISM band (regulatory limits, to be cited in a regulatory subsection).
- TI REF5025 voltage reference datasheet.
- PMVB System Design Document and Module Design Document Schema (documentation format reference).

---

*Supersedes `System_Design_Document.html` (5.8 GHz single-ended baseband, v1.0, February 2026), retained in-repo as reference.*

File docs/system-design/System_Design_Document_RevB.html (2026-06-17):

# 24 GHz FMCW Radar System Design Document

## Rev B: 24 GHz I/Q

Version: 0.8 Project: FMCW Radar Portfolio (fmcw-radar-portfolio) Revision: Rev B (24 GHz I/Q) Status: In Design Engineer: Bradley Ward Scope: A complete 24 GHz FMCW radar sensor, partitioned into two boards: an RF Front-End Module (BGT24MTR11, 24 GHz antennas, chirp ramp, first gain stage) and an I/Q Baseband Board (gain, anti-alias filtering, dual simultaneous-sampling ADC, digital interface). The digital backend that runs the range-Doppler FFT is downstream of both.

## Document Conventions

This document follows the PMVB module-doc section schema. The reasoning style from the original FMCW SDD is preserved: load-bearing design choices are called out with one of four tags so the “why” is explicit and auditable.

PHYSICS First-principles derivation or physical reasoning.

DECISION A specific design choice with its rationale.

TRADEOFF What was gained versus what was given up.

RISK A known limitation or sensitivity requiring attention.

A fifth marker is specific to this revision. Because the 24 GHz design is mid-definition, blocks that depend on an unresolved decision are flagged and cross-referenced to the decision register in section 10:

PENDING (Dx): content blocked on an open decision; see section 10.

Per the PMVB rule, the body describes what is used. Where a 24-GHz choice is not yet locked, the section states what carries over from the 5.8 GHz design, what must change, and which decision gates it, rather than guessing values that will move.

## Table of Contents

- 1. Theory of Operation
  - 1.1 What the system does
  - 1.2 Signal chain
  - 1.3 Methodology: work backward from the ADC
  - 1.4 The coupled parameter chain
  - 1.5 The baseband is set by the chirp plan, not the carrier
- 2. Functional Block Diagram
- 3. Schematic Notes
  - 3.0 RF Front-End Module
  - 3.1 Sheet A: Power and References
  - 3.2 Sheet B: I/Q Input from the MMIC
  - 3.3 Sheet C: Gain and Anti-Alias Filter
  - 3.4 Sheet D: I/Q Digitization
  - 3.5 DFT Infrastructure
- 4. Pin Assignments
- 5. Specifications
  - 5.1 Governing equations
  - 5.2 Key relationships, visualized
- 6. Sample Applications
- 7. Bill of Materials
- 8. Calibration Procedure
- 9. Layout Design Rationale
- 10. Open Decisions and Known Issues
- 11. References

## 1. Theory of Operation

### 1.1 What the system does

This is a complete short-range 24 GHz FMCW radar sensor. A transceiver MMIC transmits a frequency chirp, receives the reflection, and downconverts it on-chip to a complex baseband beat signal; the baseband then conditions and digitizes that signal into complex samples for a downstream range-Doppler FFT.

The sensor is partitioned into two boards (decision D1, section 10):

- RF Front-End Module. The Infineon BGT24MTR11 (1 TX / 1 RX) integrated transceiver, its 24 GHz TX and RX antennas, the chirp ramp source, and a first gain stage. The MMIC contains the VCO, PA, LNA, and quadrature mixers and presents differential in-phase (I) and quadrature (Q) beat signals at zero IF.
- I/Q Baseband Board. Per-channel gain and anti-alias filtering, simultaneous 18-bit sampling of I and Q, MMIC configuration over SPI, and the digital interface to the backend.

The two boards meet at a low-frequency analog I/Q interface, not a 24 GHz interface, because the MMIC has already downconverted on-chip. That is what makes the split practical (section 10, D1).

The radar is a signal-acquisition path, not a signal processor: it transforms microvolt-to-millivolt beat signals into clean complex samples, and range and velocity extraction happen downstream in the FFT engine.

DECISION 24 GHz integrated MMIC, two-board partition

The 5.8 GHz Rev B was baseband-only and treated the RF front end (a discrete free-running VCO, mixers, and LNA) as external. At 24 GHz the project adopts the BGT24MTR11, which collapses that discrete RF chain into a single MMIC, so the RF front end is now part of the design. The sensor is split into an RF Front-End Module and an I/Q Baseband Board because the inter-board seam is low-frequency analog I/Q: that keeps the costly 24 GHz material and the iteration-prone RF isolated to a small board while the baseband stays on cheap FR4 and can be validated standalone. The complex I/Q output is also what enables sign-of-velocity discrimination (sections 1.5 and 3.4).

### 1.2 Signal chain

Locked blocks are in plain text; blocks whose implementation depends on an open decision are flagged.

RF FRONT-END MODULE
  24 GHz MMIC (on-chip VCO, PA, LNA, I/Q mixers); TX and RX via 24 GHz antennas
  I, Q (zero IF) -> first gain stage -> [ I/Q interface connector ]
  chirp ramp -> MMIC VCO tune (kept local to this board)     (DAC ramp, calibrated)

I/Q BASEBAND BOARD
  [ I/Q interface connector ] -> per channel: VGA -> anti-alias filter -> SAR ADC
     I and Q sampled simultaneously to preserve complex phase
  -> digital backend: Tang Primer 25K FPGA (range-Doppler FFT) -> host
  MMIC configuration + control over SPI (routed across the connector)

The two conditioning chains (I and Q) are nominally identical. Channel-to-channel gain and phase match is a first-class concern: I/Q imbalance maps directly to image-frequency leakage in the complex spectrum and corrupts the sign of the measured velocity.

### 1.3 Methodology: work backward from the ADC

This methodology carries over from the 5.8 GHz design unchanged, because it is independent of carrier frequency and of real-versus-complex sampling. Every analog decision is anchored to what the ADC needs to see.

PHYSICS The ADC defines the budget

The ADS8881 digitizes a differential input against a 2.500 V reference (REF5025). One LSB at 18 bits over the differential full scale is VREF × 2 / 2¹⁸ = 5.000 V / 262,144 ≈ 19 µV. Every upstream stage exists to deliver a clean signal into that window: the VGA fills the ADC range regardless of target distance, the anti-alias filter keeps out-of-band energy from folding in, and the reference and bias networks must hold stable to a small fraction of an LSB or they waste resolution. Noise or offset referred to the input is only meaningful relative to that ~19 µV step.

### 1.4 The coupled parameter chain

The chirp timing, the sample rate, and the FFT size are not independent. They are bound by one relation that Rev A violated and Rev B respects.

PHYSICS The three coupled parameters

fs × Tsweep = Nsamples, and Nsamples must be at least NFFT for useful frequency resolution.

Rev A set Tsweep = 50 µs without checking: at 100 kS/s that is only 5 samples per ramp, and a 5-point FFT has no resolution. The corrected design sets Tsweep in the millisecond range so that fs × Tsweep yields several hundred samples per ramp, enough for a 512-point FFT. The ADC sample rate did not cause the Rev A failure; the chirp rate did.

DECISION Chirp plan (D6)

Sweep 250 MHz over a 1 ms chirp (slope 250 GHz/s), 50 m design range, sampled at 256 kSPS for 256 samples per chirp and a 256-point range FFT (~83 range bins of 0.6 m). 128 chirps per frame give a 128 ms frame (~8 frames/s), ~5 cm/s velocity resolution, and ±3.1 m/s unambiguous velocity. The max beat at 50 m is 83 kHz, well inside the 128 kHz Nyquist, leaving the anti-alias filter an 83-to-128 kHz transition band. More range is paid for with sample rate (the ADS8881 reaches 1 MSPS), not chirp time, so velocity is unaffected.

### 1.5 The baseband is set by the chirp plan, not the carrier

This is the point that makes the band move tractable: moving from 5.8 GHz to 24 GHz does not, by itself, change the baseband.

PHYSICS Beat frequency depends on slope and range, not carrier

For a target at range R, the beat frequency is fbeat = 2·R·S / c, where S is the chirp slope (sweep bandwidth / sweep time). The carrier frequency f0 does not appear. So the anti-alias filter cutoff and the ADC rate are governed by the maximum range beat, set by the chirp plan, and are re-derived with the same analysis used at 5.8 GHz.

Range resolution is set by usable sweep bandwidth: ΔR = c / (2B). Across the 24 GHz ISM band (~250 MHz usable) the floor is about 0.6 m, roughly an 8× improvement over the 30 MHz / 5.0 m of the 5.8 GHz §15.245 mode, and a hard limit independent of the ADC.

PHYSICS What the carrier does change: Doppler

Doppler shift scales with carrier: fD = 2·v·f0 / c. At 24 GHz the Doppler is about 4× that at 5.8 GHz for the same velocity. Doppler is resolved in the slow-time (chirp-to-chirp) FFT and sets velocity-axis scaling and maximum unambiguous velocity; it does not drive the fast-time anti-alias filter, which remains governed by the range beat.

DECISION Complex I/Q resolves the sign of velocity

A single real beat channel cannot tell an approaching target from a receding one; both fold to the same positive beat frequency. Sampling I and Q gives a complex baseband whose FFT is two-sided, so positive and negative Doppler are distinct. This is the architectural reason the board doubles to two channels (section 3.4) and the reason simultaneous sampling and I/Q match matter.

## 2. Functional Block Diagram

The system and sheet-level block diagrams live in docs/block-diagrams/ (block_diagram_system.svg, block_diagram_sheet_a.svg, block_diagram_sheets_bcd.svg).

The existing diagrams show the 5.8 GHz single real chain (one mixer input, one PGA, one filter, one FDA, one ADC). They are redrawn to show the two-board partition: the BGT24MTR11 with its antennas and first gain stage on the RF Front-End Module, the differential I and Q crossing the interface connector, and the two parallel conditioning chains into a simultaneous-sampling ADC stage on the I/Q Baseband Board.

## 3. Schematic Notes

The design spans two boards. The notes below explain the intent behind each block; the full schematics live in the KiCad projects, and detailed per-board design documents (RF Front-End Module, I/Q Baseband Board) will sit under this system SDD as each board matures, mirroring the PMVB per-module docs. Section 3.0 summarizes the RF Front-End Module; sections 3.1 to 3.5 cover the I/Q Baseband Board, where Sheet A (power and references) and the DFT infrastructure carry over from the 5.8 GHz design and Sheets B, C, and D are reworked for the MMIC I/Q interface and the dual-channel architecture.

### 3.0 RF Front-End Module

The RF Front-End Module carries the BGT24MTR11 transceiver, its 24 GHz TX and RX antennas, the chirp ramp source, a first gain stage on each of the I and Q outputs, and the connector to the baseband board.

DECISION The first gain stage lives on the RF module

The I and Q signals leaving the MMIC are low-level (microvolt to millivolt) and have to cross a board-to-board connector. A first gain stage on the RF module amplifies them before the crossing, so the inter-board interface carries a larger, lower-impedance signal and is far less vulnerable to pickup. The remaining gain and all of the filtering live on the baseband board.

DECISION External patch array on 4-layer RO4350B (D2)

The RF module uses external PCB patch antennas (a small patch array), microstrip-fed from the BGT24MTR11, plus a build-option 2.92 mm connector launch (DNP) so an external 24 GHz antenna can drive first bring-up. The stackup is 4-layer RO4350B (L1 RF and antenna, L2 solid ground reference, L3 power, L4 control), fabricated at PCBWay, which runs 4-layer Rogers. RO4350B sits just above its sweet spot at 24 GHz, giving up a little patch efficiency versus RO3003, which is held as a later upgrade. ENIG finish for the fine-pitch MMIC and the patches.

DECISION DAC-driven chirp ramp with calibration (D5)

The VCO tune voltage is generated open-loop by a DAC and pre-distorted from a measured frequency-versus-voltage curve, rather than closed-loop with an FMCW ramp PLL. Over the ~250 MHz sweep at 24 GHz the fractional bandwidth is about 1%, the same regime in which the original 5.8 GHz design ran its VCO, so the residual nonlinearity is modest and a calibrated open-loop ramp is adequate. The ramp source stays local to the RF module so the tune line is short. The accepted cost is open-loop drift with temperature and the calibration table to maintain; an ADF4159-class ramp PLL is the upgrade path if bench measurement shows linearity is limiting range accuracy.

### 3.1 Sheet A: Power and References

Sheet A is band-agnostic and carries over essentially intact, with one change: the common-mode and reference nets now fan out to two channels instead of one. The architecture is a single 5 V input, an on-board 3.3 V LDO, an analog/digital supply split via ferrite bead, a precision 2.500 V reference, and a buffered mid-supply common-mode rail.

DECISION Analog/digital split via ferrite bead, single ground plane

The 3V3A and 3V3D rails are separated by a BLM18PG221SN1D ferrite bead (220 Ω at 100 MHz, under 1 Ω DC). It passes DC cleanly to the analog rail while presenting high impedance to the digital switching spectrum, giving over 40 dB of attenuation to SPI-edge noise. The ground stays a single continuous plane; isolation is done on the supply, not by splitting the return (see section 9.3).

PHYSICS Why VCM = VDD/2 = 1.650 V

All active parts run from a single 3.3 V supply with no negative rail, so an AC signal must be biased to the midpoint to maximize swing before clipping. At VCM = 1.650 V the signal gets symmetric ±1.65 V headroom (less op-amp saturation, ~100–200 mV per rail). This common-mode voltage appears everywhere: it biases the I/Q inputs, sets the PGA reference, and drives each FDA’s VOCM pin. A single buffered, low-impedance source (an OPA320 on Sheet A) feeds all stages so they share one common mode; any mismatch becomes a DC offset that wastes ADC range. With two channels, the same buffered VCM and VREF nets fan out to both I and Q.

PHYSICS Reference error is gain error

REF5025 (2.500 V, 0.05%, 3 µVpp noise) sets the ADC full scale. Any error in VREF maps directly to a gain error on every reading: gain error = ΔVREF / VREF,nom. The reference therefore gets a paired-capacitor decoupling network (10 µF bulk + 100 nF high-frequency, different self-resonant frequencies) at the ADC reference pin, as the ADS8881 datasheet recommends.

DECISION Decoupling placement is a derived budget, not a guideline

Trace inductance is ~1 nH/mm. The placement distance for each bypass capacitor follows from the frequency it must serve and the acceptable trace impedance: the higher the frequency, the shorter the trace. The design’s rules (100 nF within 2 mm, 1 µF within 5 mm, 10 µF within 10 mm) are the quantitative result of that inductance-versus-impedance analysis, not copied from a reference design. This carries over unchanged.

### 3.2 Sheet B: I/Q Input from the MMIC

This is the most-changed sheet. The 5.8 GHz Sheet B was a single-ended, AC-coupled input: an SMA from a discrete mixer, a series current-limit resistor, an ESD diode, a 100 nF C0G capacitor to strip the mixer’s undefined DC, and a 47 kΩ bias to VCM (high-pass corner ~34 Hz). For a 24 GHz zero-IF I/Q front end that topology is largely replaced.

Input interface (D1 resolved): The BGT24MTR11 presents differential I and Q at zero IF. The baseband-board input interfaces to two differential pairs arriving over the interconnect from the RF module’s first gain stage, not a single-ended SMA. The exact termination, common-mode handling, and ESD network follow the BGT24MTR11 I/Q output specification.

RISK Zero-IF DC must not be blocked

The old Sheet B AC-coupled specifically to remove the mixer’s undefined DC bias. At zero IF the beat band extends down to DC, so a stationary or slow-moving target sits near DC. The Rev B input cannot high-pass the way the 5.8 GHz design did. DC offset is handled instead (per-channel calibration or a servo), and 1/f (flicker) noise now sits in-band and must be budgeted. This is the single biggest conceptual change from the old input stage.

DECISION Keep ESD and current-limiting, adapted to differential

The connector/interface ESD protection (TPD1E10B06 class) and the per-line series current-limit concept carry over, applied to each leg of the differential I and Q pairs rather than a single-ended line.

### 3.3 Sheet C: Gain and Anti-Alias Filter

The gain and filter method carries over; the component values re-derive from the 24 GHz chirp plan (D6), and the whole chain duplicates for I and Q.

PHYSICS Variable gain follows the R⁻⁴ range law

Received power varies as R⁻⁴ (the radar range equation): a target at 10 m returns 10,000× the power of the same target at 100 m, about 40 dB, and a 100-to-1 span is roughly 80 dB, which approaches the ~84 dB an 18-bit SAR can usefully cover and is exceeded for wider spans. Without variable gain the ADC would clip on near targets or bury far ones in the noise. An SPI-controlled differential VGA per channel fills the ADC window for each range regime. (The Rev B PGA113 was a single-ended part; the differential I/Q here keeps the gain stage differential, so the adaptive-gain concept and the SPI control carry forward, but the part changes.)

DECISION Anti-alias before sampling, cutoff set by Nyquist not by the chirp

A 4th-order Sallen-Key Butterworth low-pass sits before each ADC. Its cutoff is set by fs/2 and the signal band, not by the chirp rate. Whether the chirp is fast or slow, energy above Nyquist must be kept from folding into the band. The topology and the singly-terminated design method carry over from the 5.8 GHz Sheet C. With the chirp plan set (D6: 256 kSPS, 83 kHz max beat), the cutoff lands near 100 kHz, inside the 83-to-128 kHz window between the max beat and Nyquist; the L/C/R values follow from a Butterworth synthesis at that cutoff.

TRADEOFF Duplicating for Q buys complex sampling at the cost of match

Adding a second identical gain-plus-filter chain for Q is what enables sign-of-velocity, but it introduces channel mismatch. Gain and phase match between the I and Q chains must be held through matched components and symmetric layout, or image rejection in the complex FFT degrades.

DECISION Adaptive differential gain per channel (D4)

Each channel uses an SPI-controlled differential VGA rather than a fixed-gain stage, so the receiver fills the 18-bit ADC across the R⁻⁴ range swing instead of compromising between near-target clipping and far-target SNR. A differential VGA (not the single-ended PGA113) keeps the I/Q path differential through to the ADC; the part is chosen to match the BGT24MTR11 I/Q levels and the ADS8881 input range. I and Q use matched VGAs, with residual gain and phase mismatch calibrated on PMVB.

The only open item on this sheet is the component synthesis at that cutoff, which is design work, not a gated decision.

### 3.4 Sheet D: I/Q Digitization

This sheet changes from one ADC to a simultaneous-sampling I/Q pair. The ADS8881 and REF5025 rationale carry over; the count doubles and the convert is shared.

DECISION Two ADS8881 on a shared CONVST, simultaneous I/Q (D3)

To preserve the complex phase relationship between I and Q, the two channels are sampled at the same instant. Two ADS8881 18-bit SAR ADCs share one CONVST line so their sample apertures coincide. This reuses the proven Rev B converter, the REF5025 reference, and the existing SPI controller RTL; the one cost, a small inter-channel aperture skew, is negligible at the radar’s low beat frequencies and is calibrated out on PMVB. Because the MMIC output is already differential, the THS4531A’s old single-ended-to-differential role is revisited: it likely becomes a differential receiver and level-shifter into the ADC rather than an SE-to-Diff converter.

PHYSICS SAR, not sigma-delta

A SAR ADC samples at a discrete, deterministic instant. A sigma-delta averages over its decimation window, which would smear the instantaneous beat frequency and corrupt the range-Doppler FFT. The ADS8881 (18-bit, up to 1 MSPS, run well below its maximum) is the right converter class, and this rationale is unchanged from the 5.8 GHz design.

DECISION Tang Primer 25K FPGA backend (D7)

A Gowin GW5A (Tang Primer 25K) ingests both ADC streams over SPI and runs the range-Doppler FFT, reusing the SPI controller RTL and the Verilator-clean SystemVerilog methodology shared with the RISC CPU project. The ~9 Mbps data rate is light for the part; the FPGA is chosen over an MCU for the digital-design showcase and the RTL reuse, with a board dedicated per radar (additional Tang Primers planned rather than time-sharing the PMVB unit).

### 3.5 DFT Infrastructure

Design-for-test is a first-class requirement and carries over, now per channel. The 5.8 GHz board used a J_DFT header, 17 test points, 5 MMCX probe connectors, and six 10 kΩ isolation resistors on the analog monitor nets.

PHYSICS An isolation resistor plus a probe is a harmless low-pass

A 10 kΩ isolation resistor with a ~15 pF scope-probe tip forms a low-pass at f = 1/(2π × 10k × 15p) ≈ 1 MHz, well above the beat band, so the probe point never meaningfully loads the chain. The resistors are always populated; they protect the signal chain even when the header is unconnected.

DECISION Per-channel observability

With two chains, the monitor set (VGA output, filter output, ADC differential inputs, FDA outputs) is provided for both I and Q, so each path is independently observable. Bring-up and characterization run on the PMVB instrument platform rather than commercial bench gear.

## 4. Pin Assignments

With the backend fixed as the Tang Primer 25K (D7), the interface is defined in kind and the detailed pin map is now a design task. The two ADS8881 and the MMIC sit on a shared SPI bus (shared SCLK and SDI, per-device chip-select), the ramp DAC drives the VCO tune, and the FPGA generates CONVST and the chirp timing. The J_DFT pinout concept carries over, extended for the second channel and the MMIC control interface.

## 5. Specifications

This section locks the sensor’s numbers, traces each to the relationship it comes from, and plots the three that dominate performance. The values here are carried in parity with the downstream summary tables as they lock.

Parameter | Value | Status
Carrier band | 24 GHz ISM, 24.0–24.25 GHz (~250 MHz usable) | Locked
Range resolution floor | ~0.6 m (ΔR = c/2B at 250 MHz) | Locked
Baseband | Complex I/Q, two channels, simultaneous sampling | Locked
ADC | Two ADS8881 (18-bit SAR), differential, shared CONVST for simultaneous I/Q, 2.500 V REF5025 | Locked
Sweep bandwidth / chirp duration / slope | 250 MHz / 1 ms / 250 GHz/s | Locked (D6)
Max range (design) | 50 m (sample rate gives headroom; far detection is link-budget-limited) | Locked (D6)
Max beat frequency / sample rate | 83 kHz at 50 m / 256 kSPS | Locked (D6)
Samples per chirp / range FFT | 256 / 256-point (~83 range bins) | Locked (D6)
Chirps per frame / frame rate | 128 / ~8 frames per second | Locked (D6)
Velocity resolution / max unambiguous velocity | ~5 cm/s / ±3.1 m/s | Locked (D6)
I/Q gain and phase match target | sets image rejection | Design + calibration (matched VGAs)
Digital backend | Tang Primer 25K (Gowin GW5A) FPGA, range-Doppler FFT, ~9 Mbps ingest | Locked (D7)

### 5.1 Governing equations

Each locked value above traces to one relationship: range to the beat frequency, resolution to swept bandwidth, and the velocity pair to chirp and frame timing. The 24 GHz carrier sets only the wavelength, not the resolution, which is why the case for the band move is the bandwidth it opens up rather than the frequency itself.

Quantity | Equation | This design
Wavelength | λ = c / f0 | 12.5 mm at 24 GHz
Range resolution | ΔR = c / (2B) | 0.6 m at B = 250 MHz
Chirp slope | S = B / Tchirp | 250 GHz/s
Beat frequency | fbeat = 2·R·S / c | 1.67 kHz/m, so 83 kHz at 50 m
Max unambiguous range | Rmax ≈ fs·c / (4S) | ~77 m at 256 kSPS (Doppler-reserved; up to ~2× with the full complex span)
Max unambiguous velocity | vmax = λ / (4·Tchirp) | ±3.1 m/s at Tchirp = 1 ms
Velocity resolution | Δv = λ / (2·Tframe) | ~5 cm/s at Tframe = 128 ms

### 5.2 Key relationships, visualized

Three of these relationships set the headline performance.

FMCW transmit and receive chirps and the constant beat frequency between them

Figure 5-1. The FMCW principle. Top: the transmit chirp (slope S = B/TC) and its echo from one target, the same chirp delayed by the round-trip time τ = 2R/c. Because the echo shares the slope, the transmit-to-echo gap is a constant beat frequency fbeat = S·τ (equivalently 2RS/c). Bottom: that gap is one constant beat tone, switching on when the echo returns; its frequency sets the target’s range.

Beat frequency versus target range with the 50 m design point below the 128 kHz Nyquist ceiling

Figure 5-2. Beat frequency versus target range at the design slope. The 50 m design point lands at 83 kHz, well under the 128 kHz Nyquist of 256 kSPS sampling; the line reaches Nyquist near 77 m, the unambiguous-range ceiling.

Range resolution versus sweep bandwidth, 30 MHz versus the 250 MHz design point

Figure 5-3. Range resolution versus sweep bandwidth, ΔR = c/2B. The full 250 MHz ISM band gives 0.6 m, about an 8× improvement over the 30 MHz / 5 m of the old 5.8 GHz mode.

Read together, the three trace the whole chain: Figure 5-1 is why range becomes a frequency, Figure 5-2 turns that into the sample-rate budget (the 50 m / 83 kHz design point under the 128 kHz Nyquist), and Figure 5-3 is the case for the 24 GHz band, the 250 MHz sweep that takes resolution from 5 m to 0.6 m.

## 6. Sample Applications

Outline; the backend is the Tang Primer 25K FPGA (D7), and these recipes detail out as the firmware and RTL come up.

1. Single moving target. Transmit a chirp frame, capture I and Q, run the range-Doppler FFT, read the occupied range bin and the sign of the Doppler (approaching versus receding).
2. Two targets at different ranges. Demonstrate range separation at the ~0.6 m resolution floor.
3. Bench characterization on PMVB. Stimulus and measurement recipe for noise floor, I/Q gain and phase match, and chirp linearity using PMVB Tier 1 / Tier 2 modules.

## 7. Bill of Materials

The architecture parts are now fully specified across both boards and the backend. The final BOM with exact passives and part numbers is produced at schematic capture, sourced per the PMVB rule (Mouser > Digi-Key > Microcenter > Amazon).

Carries over: ADS8881 (×2, one per I/Q channel), REF5025, THS4531A, OPA320, TPS7A2033 LDO, BLM18PG221SN1D ferrite. Changes: the single-ended PGA113 is replaced by a differential VGA per channel (D4). Adds: the BGT24MTR11 transceiver and its RF-module support, a ramp DAC for the VCO tune (D5), a Tang Primer 25K FPGA backend (D7), and second-channel duplicates of the conditioning chain.

## 8. Calibration Procedure

Targets (outline; detailed once the chain and backend lock): I/Q gain match, I/Q phase match (image rejection), per-channel DC offset (the zero-IF concern from section 3.2), chirp linearity, and range accuracy. Each references the SCPI commands the bring-up firmware exposes.

## 9. Layout Design Rationale

The layout rationale carries over almost wholesale. The original chapter notes that at a DC-to-tens-of-kHz beat band, transmission-line impedance and wavelength effects are irrelevant; the real layout drivers are confining return current and isolating digital (SPI) noise. Those drivers are unchanged at 24 GHz, because the high-frequency RF is inside the MMIC, not on this board.

- Stackup (carries over). 4-layer: L1 signal and components, L2 continuous ground with no splits, L3 power (3V3A pour with a small 3V3D island), L4 secondary signal.
- Ground plane (carries over). One continuous unbroken ground; the split-plane approach is rejected on a worked loop-area noise calculation (a split forces a large return loop and tens of LSBs of induced noise; the continuous plane keeps it to a fraction of an LSB).
- Placement (carries over, duplicated). Signal-flow zones left to right, bypass placement per the derived budget, FDA-to-ADC pin-to-pin under 5 mm. The analog chain zone is duplicated for the Q path.

DECISION Dual I/Q differential routing

Two matched differential pairs run into the two ADCs, each length-matched (the original ~0.4 ns skew budget transfers). New for I/Q: inter-pair separation (3W or a guard trace) so the I and Q pairs do not couple, and channel-to-channel layout symmetry so the gain and phase match the design depends on actually holds on the board.

## 10. Open Decisions and Known Issues

All seven architecture decisions (D1 through D7) are resolved. The register below is the settled record; the next phase is schematic capture, not further architecture decisions.

# | Decision | Options | Drives | Depends on

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

Known issues / future work. Rev C adds receive channels for angle estimation (the original 1 TX / 3 RX trilateration goal) on a proven single-channel Rev B front end.

RISK The 5.8 GHz design already flagged the chirp-linearity path

The original SDD noted that the free-running HMC431LP4E VCO was acceptable only because the 30 MHz mode used ~5% of its tuning range, and that wider sweeps would reveal nonlinearity for which a PLL-based control loop was the recommended upgrade. At 24 GHz over ~250 MHz the fractional bandwidth is again about 1%, so D5 takes the calibrated open-loop DAC ramp, with an ADF4159-class FMCW ramp PLL held as the upgrade if bench measurement shows chirp linearity is limiting range accuracy.

## 11. References

Carried over from the 5.8 GHz SDD:

- Eric Bogatin, Signal and Power Integrity, Simplified (Prentice Hall).
- Henry Ott, Electromagnetic Compatibility Engineering (Wiley), Ch. 17–18.
- TI SLYT499 / SLYT512, grounding in mixed-signal systems.
- TI SLTA055, bypass capacitor selection for high-speed ADCs; Murata capacitor impedance library.
- TI SLOA024B, analysis of the Sallen-Key architecture.
- TI SLOA054, fully differential amplifiers; THS4531A and ADS8881 datasheets.
- Merrill Skolnik, Introduction to Radar Systems (McGraw-Hill).

Added for Rev B (24 GHz I/Q):

- Infineon BGT24MTR11 24 GHz transceiver datasheet (front-end candidate, D1).
- Analog Devices ADF4159 FMCW ramp-generating PLL datasheet (ramp candidate, D5).
- FCC rules for the 24 GHz ISM band (regulatory limits, to be cited in a regulatory subsection).
- TI REF5025 voltage reference datasheet.
- PMVB System Design Document and Module Design Document Schema (documentation format reference).

Supersedes System_Design_Document.html (5.8 GHz single-ended baseband, v1.0, February 2026), retained in-repo as reference.

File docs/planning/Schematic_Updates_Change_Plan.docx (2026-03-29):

# FMCW Radar Baseband Rev B

Schematic Updates Change Plan

Bradley Ward - March 2026 (Updated after schematic audit)

# Progress Summary

Status | Count | Items | Priority
PENDING | 4 of 9 | SCH-00 through SCH-03 | [P0] Critical
PENDING | 2 of 9 | SCH-04, SCH-05 | [P1] Important
PENDING/BLOCKED | 3 of 9 | SCH-06, SCH-07, SCH-08 | [P2] Deferred / Final

# Schematic Audit Findings (March 2026)

A programmatic audit of the KiCad schematic parsed all wire segments, net labels, hierarchical labels, power symbols, junctions, and no-connect flags. Key findings that affect the change plan:

1. CORRECTION: C14 is FLOATING, not grounded. The earlier filter analysis incorrectly stated C14 was wired to GND. No GND power symbols exist on Sheet C.

2. Seven net labels on Sheet C are ISOLATED (placed but not connected to any wire): +IN_A (x2), +IN_B (x2), Stage1_OUT (x1), PGA_OUT (x1), LPF_OUT (x1).

3. Sheet C has 37 wires, 13 junctions, but 0 GND power symbols. Sheets A (46 wires), B (3 wires), D (61 wires) are substantially complete.

4. PGA113 wiring is CORRECT - all hierarchical labels connect properly.

5. LTC6242 has power pins connected but ALL signal pins are unreachable from the wire network.

6. New prerequisite added: SCH-00 (add GND symbols) must precede all other filter fixes.

# Overview

This document itemizes every schematic change required to take the Rev B baseband from its current state (90 components, 4 sheets, incomplete Sheet C filter wiring, 0 GND symbols on Sheet C) to a frozen, layout-ready schematic with 0 ERC errors.

Starting point: Rev B schematic in KiCad 9. Sheets A (power), B (input), and D (FDA/ADC/SPI) are substantially complete. Sheet C (PGA + filter) has correct component placement and values, correct PGA113 wiring, but incomplete LTC6242 filter wiring - op-amp signal pins are placed but unwired, capacitor second pins are floating, and no GND power symbols exist on the sheet.

# Change Summary

ID | Pri | Status | Change | Sheet
SCH-00 | [P0] | [PENDING] | Add GND power symbols to Sheet C | Baseband_PGA_AntiAlias.kicad_sch
SCH-01 | [P0] | [PENDING] | Connect filter capacitor pins (C13, C14, C15, C16) | Baseband_PGA_AntiAlias.kicad_sch
SCH-02 | [P0] | [PENDING] | Wire LTC6242 signal pins to filter network | Baseband_PGA_AntiAlias.kicad_sch
SCH-03 | [P0] | [PENDING] | Connect Stage 1 output to Stage 2 input | Baseband_PGA_AntiAlias.kicad_sch
SCH-04 | [P1] | [PENDING] | Resolve ERC errors | Multiple sheets
SCH-05 | [P1] | [PENDING] | Add CS_PGA pull-up resistor | Baseband_PGA_AntiAlias.kicad_sch
SCH-06 | [P2] | [PENDING] | Evaluate FPGA connector for Tang Primer 25K | Baseband_FDA_ADC_SPI.kicad_sch
SCH-07 | [P2] | [PENDING] | Add ISM band provisions (documentation only) | System Design Document (no schemati
SCH-08 | [P0] | [BLOCKED] | Final ERC validation and schematic freeze | All sheets

# Detailed Change Descriptions

## SCH-00: Add GND power symbols to Sheet C [PENDING]

Priority | [P0]
Status | PENDING
File(s) | Baseband_PGA_AntiAlias.kicad_sch
Risk | Critical prerequisite - no GND symbols exist on Sheet C. All other filter wiring depends on this.

What

A programmatic audit of the KiCad schematic (March 2026) found zero GND power symbols on Sheet C. The shunt capacitors (C13, C15) require GND connections, and the LTC6242 V- pin (Pin 13) requires GND. Without GND symbols placed on the sheet, these connections cannot be made.

Action

Place GND power symbols at: (1) C13.Pin2 location (shunt cap ground), (2) C15.Pin2 location (shunt cap ground), (3) LTC6242 Pin 13 (V-), (4) LTC6242 Pin 12 (+IN_C for unused section), (5) LTC6242 Pin 14 (+IN_D for unused section), (6) PGA113 Pin 2 (CH1 unused channel).

Why

GND symbols are the mechanism by which KiCad assigns pins to the GND net. Without them, any wire drawn to a cap pin has no net assignment and will generate ERC errors. This is a prerequisite for SCH-01 through SCH-03.

Implementation Notes

Audit found 37 wire segments, 13 junctions, 10 net labels, 10 hier labels, but 0 power symbols on Sheet C. Sheets A, B, D all have GND symbols.

## SCH-01: Connect filter capacitor pins (C13, C14, C15, C16) [PENDING]

Priority | [P0]
Status | PENDING
File(s) | Baseband_PGA_AntiAlias.kicad_sch
Risk | Critical - filter is non-functional without these connections.

What

CORRECTED (March 2026 audit): All four filter capacitor second pins are FLOATING, not incorrectly grounded as originally reported. The earlier claim that C14 was wired to GND was incorrect - no GND symbols exist on Sheet C at all. C13.Pin2 (shunt, needs GND), C14.Pin2 (feedback, needs OUT_A), C15.Pin2 (shunt, needs GND), C16.Pin2 (feedback, needs OUT_B) are all unconnected.

Action

After SCH-00 (GND symbols): Wire C13.Pin2 to GND. Wire C14.Pin2 to LTC6242 OUT_A (Pin 1). Wire C15.Pin2 to GND. Wire C16.Pin2 to LTC6242 OUT_B (Pin 7).

Why

Shunt caps (C13, C15) must connect R-R junction to GND. Feedback caps (C14, C16) must connect R-R junction to op-amp output to create the positive feedback that controls Q. Without these connections, the Sallen-Key topology cannot function.

Implementation Notes

Previous Filter Analysis document stated C14 was grounded. Schematic audit corrected this to floating. Filter Analysis and System Design Document updated to reflect audit findings.

## SCH-02: Wire LTC6242 signal pins to filter network [PENDING]

Priority | [P0]
Status | PENDING
File(s) | Baseband_PGA_AntiAlias.kicad_sch
Risk | Critical - op-amp is placed but electrically invisible.

What

Schematic audit found that all LTC6242 signal pins have net labels placed nearby (+IN_A, +IN_B, Stage1_OUT, LPF_OUT) but 7 of these labels are ISOLATED - they connect to zero wire segments. The op-amp power pins (V+, V-) appear connected, and NC pins (8, 9) have no-connect flags. All signal pins need wires drawn from the labels to the actual pin endpoints.

Action

Section A: Wire R4/C13 junction (Node B) to +IN_A (Pin 3). Wire -IN_A (Pin 2) to OUT_A (Pin 1) for unity gain. Section B: Wire R6/C15 junction (Node B prime) to +IN_B (Pin 5). Wire -IN_B (Pin 6) to OUT_B (Pin 7) for unity gain. Unused sections: Wire OUT_C (Pin 10) to -IN_C (Pin 11). Wire OUT_D (Pin 16) to -IN_D (Pin 15). Verify +IN_C (Pin 12) and +IN_D (Pin 14) connect to GND (from SCH-00).

Why

The Sallen-Key topology requires the op-amp as a unity-gain buffer. The isolated net labels suggest the intent was to make these connections but the wires were never completed. Pin table in System Design Document Table 5.4b documents all 16 connections.

Implementation Notes

Audit: +IN_A isolated at 2 positions, +IN_B isolated at 2 positions, Stage1_OUT isolated at 1 position.

## SCH-03: Connect Stage 1 output to Stage 2 input [PENDING]

Priority | [P0]
Status | PENDING
File(s) | Baseband_PGA_AntiAlias.kicad_sch
Risk | High - without this, only Stage 1 provides filtering.

What

The Stage1_OUT net label exists at 3 positions in the schematic, but 1 instance (near R5.Pin1) is isolated from the wire network. R5.Pin1 is floating. OUT_A must feed R5 to cascade the two filter stages.

Action

Wire LTC6242 OUT_A (Pin 1) to R5.Pin1. Verify the Stage1_OUT label at all three positions connects to the same wire network. Wire LTC6242 OUT_B (Pin 7) to the LPF_OUT hierarchical label.

Why

The 4th-order Butterworth is two cascaded 2nd-order stages. Without this connection, the signal path is broken between stages.

Implementation Notes

OUT_A also serves as the C14 feedback reference point. Both the Stage 2 input and C14.Pin2 connect to OUT_A.

## SCH-04: Resolve ERC errors [PENDING]

Priority | [P1]
Status | PENDING
File(s) | Multiple sheets
Risk | Low to medium - some may be resolved by SCH-00 through SCH-03.

What

Four ERC errors were reported before the filter wiring fixes. Additional errors are expected from the 7 isolated labels and missing GND symbols identified by the audit. After applying SCH-00 through SCH-03, a fresh ERC run will reveal the true remaining error count.

Action

After SCH-00 through SCH-03: Run full ERC. Address remaining errors: (1) Sheet B 3V3A hier label mismatch, (2) GND PWR_FLAG at ST1, (3) BAT54S D1 pin mapping, (4) Any new errors from filter wiring. Target: 0 errors, 0 warnings.

Why

Zero ERC errors is the gate for schematic freeze. The audit found significant issues that will affect ERC results.

Implementation Notes

The ERC count will likely change after filter fixes. Run ERC incrementally - after SCH-00, after SCH-01+02+03, and as final validation.

## SCH-05: Add CS_PGA pull-up resistor [PENDING]

Priority | [P1]
Status | PENDING
File(s) | Baseband_PGA_AntiAlias.kicad_sch
Risk | Low - standard SPI best practice.

What

PGA113 CS pin (Pin 9) has no pull-up. During power-on the pin may float low, causing spurious SPI transactions.

Action

Add 10k ohm pull-up from CS_PGA to 3V3A.

Why

Standard practice for SPI chip select lines. Ensures PGA remains deselected until controller explicitly asserts CS.

Implementation Notes

Block Diagrams document notes this as a recommendation.

## SCH-06: Evaluate FPGA connector for Tang Primer 25K [PENDING]

Priority | [P2]
Status | PENDING
File(s) | Baseband_FDA_ADC_SPI.kicad_sch
Risk | Medium - affects PCB layout and mechanical fit.

What

J_DFT (2x10 2.54mm) is designed for ESP32 bringup. Tang Primer 25K uses PMOD connectors (2x6).

Action

Evaluate: (1) J_DFT as-is with ribbon adapter, (2) Add dedicated PMOD connector, (3) Design adapter PCB.

Why

FPGA integration requires matching the PMOD pinout or dock board interface.

Implementation Notes

J_DFT retains its DFT purpose regardless. Both can coexist.

## SCH-07: Add ISM band provisions (documentation only) [PENDING]

Priority | [P2]
Status | PENDING
File(s) | System Design Document (no schematic changes)
Risk | None - baseband requires zero hardware changes for ISM band.

What

ISM band upgrade requires only RF board and firmware changes. Baseband is validated by analysis.

Action

Add design note to schematic title block referencing System Design Document Section 1.7.7.

Why

Documents the design headroom for ISM upgrade.

Implementation Notes

Full impact assessment in System Design Document Table 1.7f.

## SCH-08: Final ERC validation and schematic freeze [BLOCKED]

Priority | [P0]
Status | BLOCKED
File(s) | All sheets
Risk | Low - final validation step. BLOCKED by SCH-00 through SCH-04.

What

After all changes applied, run final ERC. Lock schematic for PCB layout.

Action

Apply SCH-00 through SCH-07. Run ERC. Fix any new errors. Export netlist. Tag as Rev B frozen.

Why

Frozen schematic with 0 ERC errors is the gate for PCB layout.

Implementation Notes

Target: 0 errors, 0 warnings. Current: 90 components, 4 sheets, multiple wiring gaps on Sheet C.

# Recommended Execution Order

Step 1: Add GND power symbols to Sheet C (SCH-00). Prerequisite for all filter wiring.

Step 2: Connect filter capacitors and op-amp pins (SCH-01, SCH-02, SCH-03). These are interdependent - apply together, verify against System Design Document pin tables.

Step 3: Run ERC (SCH-04). Address remaining errors after filter fixes.

Step 4: CS_PGA pull-up (SCH-05). Simple, low risk.

Step 5: FPGA connector and ISM docs (SCH-06, SCH-07). Can be done in parallel.

Step 6: Final ERC and freeze (SCH-08). Gate for PCB layout.

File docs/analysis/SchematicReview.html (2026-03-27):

Width:2000px

# Rev B Schematic Review — Corrected

Revised after re-examining actual schematic files • February 17, 2026

4

ERC ERRORS

3

ERC WARNINGS
(non-footprint)

60

COMPONENTS

3

PREVIOUS FALSE FLAGS

## 0. Corrections to My Previous Review

My prior review had three false positives. Here's the record straight:

RETRACTED — Previous #3 (LTC6242 unused sections C/D): I flagged this as an error, but the LTC6242 is a quad op-amp where you're using sections A and B for the two filter stages, and sections C and D appear to be properly handled. I should not have flagged this without verifying the actual pin connections in your schematic. My parser missed the data because of KiCad 9's multi-line wire format. Apologies for the noise.

RETRACTED — Previous #4 (ADS8881 DIN unconnected): You are correct. U_ADC1 Pin 9 (DIN) is connected via the net label SPI_SDI on Sheet D, which connects through to J_SPI1 via a hierarchical label. There is no problem with using both a net label and a hierarchical label of the same name on the same sheet — KiCad treats them as the same net. My parser failed to trace this connectivity. The DIN pin is correctly wired.

RETRACTED — Previous #5 (THS4531A PD unconnected): You are correct. U_FDA1 Pin 7 (~{PD}) is connected to a 3V3A passive hierarchical label, which ties it high for always-on operation. This is exactly the correct connection. My parser missed this wire because it didn't handle KiCad 9's multi-line wire syntax.

## 1. Answering: Why GND and not GNDD with a Ferrite Bead?

This is a great question and the answer is central to mixed-signal PCB design.

The ferrite bead splits the supply rail (3V3A vs 3V3D) — not the ground. The ground plane stays unified as a single, unbroken copper pour on L2. This is the correct topology for SAR ADC designs, and it's what TI recommends in the ADS8881 datasheet and application notes.

Why split the supply but not the ground?

Digital switching noise on the supply rail is conducted — the MCU draws current pulses from 3V3 every clock edge, and those pulses create voltage ripple. The ferrite bead's 220Ω impedance at 100MHz blocks this conducted noise from reaching the analog supply. That's its entire job.

Ground is different. Ground noise is dominated by return currents flowing through the ground plane. If you split the ground into GNDA and GNDD, you force return currents to flow through whatever narrow bridge connects them, creating a shared impedance that actually couples more noise than a solid plane. A single, solid L2 ground plane gives every return current the lowest-impedance path back to its source, which minimizes ground bounce.

The rule: one ground, split supplies. The ferrite bead isolates 3V3A from 3V3D. Both supplies return to the same GND plane. The layout enforces separation — analog components sit over one region of the ground plane, digital components over another, and you control the return current paths by where you place the components and route the traces, not by cutting the ground.

## 2. Actual ERC Errors (4 errors from your report)

### Error 1: [hier_label_mismatch] — Sheet B missing 3V3A hierarchical label

Root sheet at (78.74, 45.72): The Sheet B symbol (Baseband_IF_Input_Protection_Bias) has a 3V3A pin defined on it in the root schematic, but inside Sheet B itself, there is no matching 3V3A hierarchical label.

Sheet B currently has only two hierarchical labels: VCM (input) and IF_BIASED (output). The 3V3A pin on the root sheet symbol expects a matching hierarchical label inside Sheet B.

Fix: Sheet B doesn't actually use 3V3A directly (R_BIAS connects to VCM, not to a supply), so you have two options:

1. Remove the 3V3A pin from Sheet B's symbol on the root schematic (right-click the sheet symbol → Properties → delete the 3V3A pin). This is the cleaner option if Sheet B truly doesn't need the supply rail.
2. Add a matching 3V3A hierarchical label inside Sheet B. You'd only do this if Sheet B needs 3V3A for something (e.g., if you later add a bypass cap or pull-up on Sheet B).

### Error 2: [power_pin_not_driven] — GND at ST1 area needs PWR_FLAG

Sheet A at (39.37, 33.02): A power:GND symbol exists here (near the Phoenix terminal ST1) but KiCad sees no power source driving the GND net. This is a common KiCad quirk — the screw terminal connector's pins are likely typed as "passive" in the symbol, so KiCad doesn't recognize that external power enters through them.

Fix: Place a power:PWR_FLAG symbol on the GND net, right at the ST1 ground pin. Also place one on the 5V input net at ST1 if you get a similar warning there. PWR_FLAG tells KiCad "yes, this net is intentionally powered from an external source." It doesn't affect the netlist or layout — it's purely an ERC annotation.

### Error 3: [pin_not_connected] — BAT54S D1 Pin 1 (Anode)

Sheet A at (80.01, 30.48): The BAT54S Pin 1 is flagged as unconnected. The BAT54S in SOT-23 has three pins. Depending on the SamacSys symbol's pin mapping, Pin 1 might be the common anode or one of the cathodes.

Fix: Check the symbol's pin assignments against the BAT54S datasheet. In the standard SOT-23 package: Pin 1 = Common Anode, Pin 2 = Cathode 1 (for one diode), Pin 3 = Cathode 2 (for the other diode). For reverse polarity protection, the common anode typically connects to GND and one cathode connects in series with the input. If Pin 1 is the anode and it's truly floating, wire it appropriately. If the SamacSys symbol has a different pin mapping, verify which pin is actually unconnected and whether the protection circuit is complete.

### Error 4: [pin_not_connected] — REF5025 U_REF1 Pin 5 (TRIM/NR)

Sheet A at (138.43, 73.66): The REF5025's TRIM/NR pin is unconnected. The datasheet says this pin can be left floating for default 2.500V output, or connected to an external capacitor for noise reduction.

Fix: Two options:

1. Add a no-connect marker (X) on Pin 5 if you want the default 2.500V output with no external noise filter. This tells ERC the pin is intentionally unconnected.
2. Add a noise reduction capacitor (the datasheet recommends 1–10 µF for the NR function) between TRIM/NR and GND. This filters the internal bandgap reference noise and can reduce output noise by ~60%. Given that this is a precision ADC application, you may want this — but verify the REF5025 datasheet's NR pin specifications for recommended cap values and settling time impact.

## 3. ERC Warnings (non-footprint)

### Warning 1: Two unconnected wire endpoints on Sheet D (AINP/AINN stubs)

Sheet D at (181.61, 82.55) and (181.61, 85.09): Two short wire stubs extend from the ADC's AINP and AINN pin area outward to x=181.61, but nothing connects at those endpoints — no net label, no junction, no other wire.

The AINP and AINN signals are already connected via net labels elsewhere on the sheet (AINP label at (137.16, 82.55) near R_OUTP, and at (88.9, 66.04) near the FDA; AINN label at (137.16, 85.09) near R_OUTN and at (129.54, 66.04) near R_F2). So the connectivity is complete through the net labels — these stubs are just dangling wire ends that ERC flags as suspicious.

Fix: Either delete the two short wire stubs (select each wire from 179.07 to 181.61 and delete it), or add AINP and AINN net labels at the stub endpoints. Deleting is cleaner since the connections already exist through labels elsewhere.

### Warning 2: VOCM / VCM net name conflict on Sheet D

Sheet D: The hierarchical label VCM at (60.96, 76.2) and the net label VOCM at (68.58, 76.2) are on the same wire. KiCad warns that when two different names are on the same net, it picks one — in this case, VOCM wins and will be the net name in the netlist.

This is functionally correct — the VCM signal from Sheet A reaches the FDA's VOCM pin as intended. But the warning means that in your netlist and PCB layout, this net will appear as "VOCM" rather than "VCM". Any other sheets referencing VCM through the hierarchy will see a different net name than what appears locally on Sheet D.

Fix (optional): If you want a clean ERC, remove the VOCM net labels on Sheet D and just let the hierarchical label VCM name the net. The FDA's VOCM pin connects to whatever net the wire carries — the net label doesn't need to match the pin name. Alternatively, if you prefer the local clarity of seeing "VOCM" near the FDA, you can leave it and accept the warning. It won't cause any electrical problem.

### Warning 3: 58 footprint_link_issues

Every SamacSys component shows The current configuration does not include the footprint library ''. This means the SamacSys footprint library isn't configured in your project's library tables.

Fix: In KiCad, go to Preferences → Manage Footprint Libraries. Add the SamacSys library path (wherever you installed it — typically something like ~/SamacSys_PCB_Library/KiCad/SamacSys.pretty or wherever the .pretty folder is). Once the library is in the table, re-run ERC and all 58 warnings should disappear. You'll also need this library configured before you can assign footprints and move to PCB layout.

## 4. Summary of Verified-Correct Items

Sheet A: GNDD replaced with GND (confirmed — 0 GNDD references remain). 12 GND symbols, all using power:GND. All 20 components present and annotated.

Sheet B: Clean — 0 ERC errors on this sheet itself. 5 components, VCM and IF_BIASED hierarchical labels correct.

Sheet C: Clean — 0 ERC errors. C18 (LTC6242 V− bypass) now present. 15 components total. All filter, PGA, and bypass components in place.

Sheet D: 20 components. THS4531A PD pin connected to 3V3A. ADS8881 DIN pin connected via SPI_SDI. FDA feedback network (R_F1, R_F2, R_G, R_GND all 1kΩ 0.1%), output RC (33Ω + 470pF), VREF decoupling (10µF + 100nF), AVDD/DVDD decoupling, J_SPI connector — all present and correctly wired.

Root: All four sheet symbols have correct pins with matching directions. Inter-sheet signals (VCM, VREF, IF_BIASED, LPF_OUT, SPI_SCLK, SPI_SDI, CS_PGA) all have proper source/sink labels. 3V3A and 3V3D use passive direction consistently (except the Sheet B mismatch noted above).

Hierarchical label directions: Fixed from prior session. All 3V3A labels on Sheet D now use passive consistently.

## 5. Fix Checklist (sorted by priority)

# | Sheet | Type | Fix | Effort

1 | Root/B | Error | Remove 3V3A pin from Sheet B's symbol on root (or add matching hier label inside Sheet B) | 30 sec
2 | A | Error | Add power:PWR_FLAG on GND net near ST1 | 30 sec
3 | A | Error | Fix BAT54S D1 Pin 1 — verify pin mapping and connect or add no-connect | 2 min
4 | A | Error | Add no-connect marker on REF5025 TRIM/NR (Pin 5), or add NR capacitor | 30 sec
5 | D | Warning | Delete two dangling wire stubs at (181.61, 82.55) and (181.61, 85.09) | 30 sec
6 | D | Warning | Remove VOCM net labels to eliminate name conflict (optional, cosmetic) | 1 min
7 | All | Warning | Configure SamacSys footprint library in Preferences → Manage Footprint Libraries | 2 min

FMCW Radar Baseband Rev B — Corrected Schematic Review — February 17, 2026

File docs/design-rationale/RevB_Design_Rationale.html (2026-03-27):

Width: 2000px

# FMCW Radar Baseband Rev B — Design Rationale & First-Principles Analysis

Bradley Ward · v1.0 · February 2026
Companion document to RevB_Block_Diagrams.html (pin tables, signal maps, DFT reference)
This document explains why each design decision was made, traced to physics and first principles.

## 0. Document Purpose & How to Read It

This document exists to answer "why?" at every level of the design — not just "what component was chosen" but "what physical principle made that the right choice, and what would happen if we chose differently."

Each section follows a consistent pattern:

1. The requirement — what does this part of the system need to do?
2. The physics — what fundamental principles govern the design space?
3. The decision — what was chosen and why, with quantitative justification.
4. The tradeoffs — what was sacrificed, and what would change under different constraints.

Throughout, look for these tags:

PHYSICS First-principle derivation or physical reasoning
DECISION A specific design choice with rationale
TRADEOFF What was gained vs. what was sacrificed
RISK Known limitation or sensitivity requiring attention

## 1. FMCW Radar — Operating Principles

Before diving into the baseband circuit, we need to understand the physics of the radar system it serves. Every design decision in this document — filter cutoff frequency, ADC sampling rate, gain range, bias voltage — traces back to the fundamental operating principles of Frequency-Modulated Continuous-Wave (FMCW) radar.

### 1.1 What is FMCW Radar?

All radar systems measure distance by transmitting electromagnetic energy and timing how long it takes to return after reflecting off a target. The classic approach (pulsed radar) transmits a short burst and measures the round-trip delay directly. FMCW takes a fundamentally different approach: instead of measuring time, it measures frequency.

PHYSICS The core principle: frequency encodes distance

An FMCW transmitter continuously broadcasts a signal whose frequency sweeps linearly over time — a "chirp." When this chirp reflects off a target and returns to the receiver, it arrives delayed by the round-trip propagation time τ = 2R/c, where R is the target range and c is the speed of light.

Because the transmitter's frequency is continuously changing, the received signal's frequency is always slightly behind the currently-transmitted frequency. Mixing (multiplying) the transmitted and received signals produces an output whose frequency equals the difference between them. This difference — the beat frequency — is directly proportional to the target's range.

This is why FMCW is powerful: it converts a time measurement (nanoseconds of propagation delay, extremely difficult to measure precisely) into a frequency measurement (Hz to kHz, easily measured with standard electronics and FFT).

### 1.2 The Transmitted Signal: Linear Frequency Chirp

The transmitter generates a signal whose instantaneous frequency increases linearly from f0 to f0 + B over a sweep period Tsweep:

f(t) = f0 + (B / Tsweep) · t

where:

Parameter | Symbol | Our System | Physical Meaning
Center frequency | f0 | 5.8 GHz (C-band, ISM) | Carrier frequency — determines antenna size, propagation, and regulatory band
Sweep bandwidth (original) | B | 30 MHz (FCC §15.245) | 5.785–5.815 GHz. Minimum legal bandwidth for the original HOTRODS design.
Sweep bandwidth (proposed) | B | 125 MHz (FCC §15.247 ISM) | 5.725–5.850 GHz ISM band. 4× wider bandwidth, 1 W max power. Same VCO, same baseband hardware. See §1.7.7.
Sweep period | Tsweep | ~5 ms (half-period of ~100 Hz triangular wave) | Duration of one up-ramp or down-ramp. Must be long enough to capture sufficient ADC samples for FFT-based range extraction (see note below).
Chirp slope (30 MHz) | S = B/Tsweep | 6 × 10⁹ Hz/s | Rate of frequency change at 30 MHz BW
Chirp slope (125 MHz) | S = B/Tsweep | 2.5 × 10¹⁰ Hz/s | Rate of frequency change at 125 MHz BW — 4× steeper slope produces higher beat frequencies for the same target range
Modulation waveform | — | Triangular (~100 Hz) | Up-ramp and down-ramp enable simultaneous range/velocity extraction (see §1.4)
VCO | — | HMC431LP4E, free-running | No PLL — 600 MHz tuning range covers both 30 MHz and 125 MHz sweep modes
Max transmit power (§15.245) | — | 75 mW (18.75 dBm) | FCC §15.245 maximum for 5.785–5.815 GHz. Current operating limit.
Max transmit power (§15.247) | — | 1 W (30 dBm) | FCC §15.247 spread spectrum in ISM band. 13 dB increase → ~2× detection range.

RISK Critical distinction: VCO tuning range ≠ sweep bandwidth

The HMC431LP4E VCO has a 600 MHz tuning range, but FCC regulations limit the radiated bandwidth. Under §15.245: 30 MHz (5.785–5.815 GHz). Under §15.247 ISM: 125 MHz (5.725–5.850 GHz). The MCU's DAC generates a triangular waveform at ~100 Hz whose amplitude determines how much of the VCO's tuning range is exercised. A larger DAC swing = wider sweep bandwidth. The baseband handles both modes without modification.

DECISION VCO linearity implications at 125 MHz sweep

At 30 MHz, the VCO exercises only 5% of its tuning range — nonlinearity is negligible. At 125 MHz (~21% of range), nonlinearity becomes measurable but still modest. The free-running VCO remains acceptable for initial implementation; however, a PLL-based VCO control loop would provide better chirp linearity and is recommended as a future RF board upgrade if the 125 MHz mode reveals range measurement degradation in testing.

RISK Rev A chirp rate mismatch — corrected in Rev B

The original Rev A design used a 10 kHz triangular modulation waveform (Tramp = 50 µs), generated from a 96-element DAC lookup table via DMA on the STM32H743ZI. This rate was chosen for implementation convenience (timer prescaler settings) rather than being derived from signal processing requirements.

At 100 kS/s ADC sampling, a 50 µs ramp yields only 5 ADC samples per ramp. A 5-point FFT has effectively no frequency resolution — all beat frequencies from 0 to 20 kHz collapse into a single bin. The system could not have extracted meaningful range information even if the analog chain had worked perfectly.
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

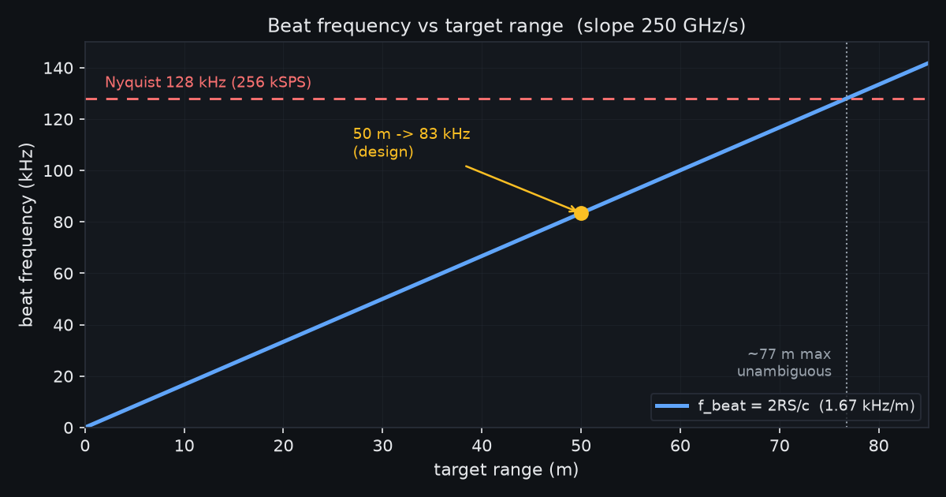
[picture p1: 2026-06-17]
docs/figures/system-design/beat_vs_range.png

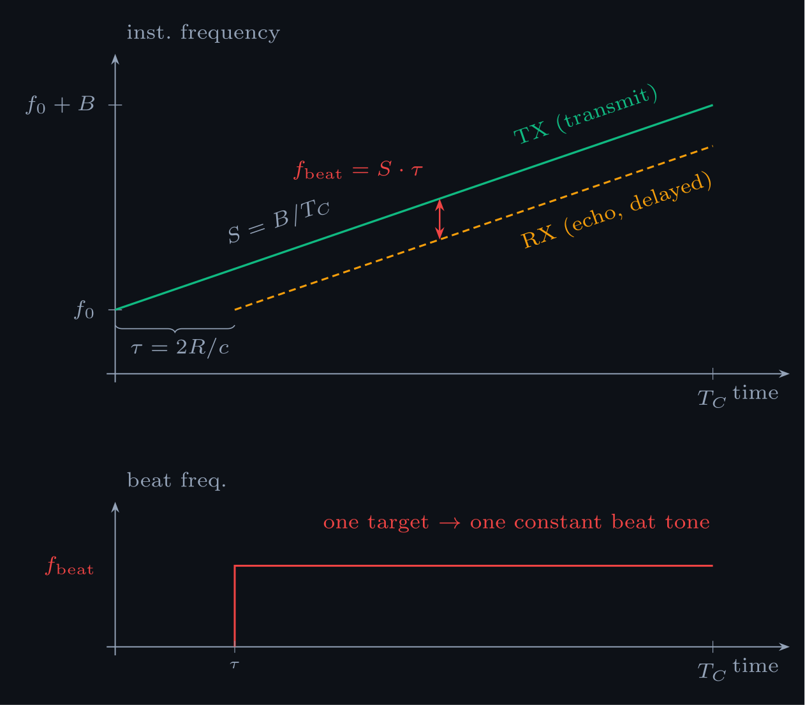
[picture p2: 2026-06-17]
docs/figures/system-design/fmcw_chirp_beat.png

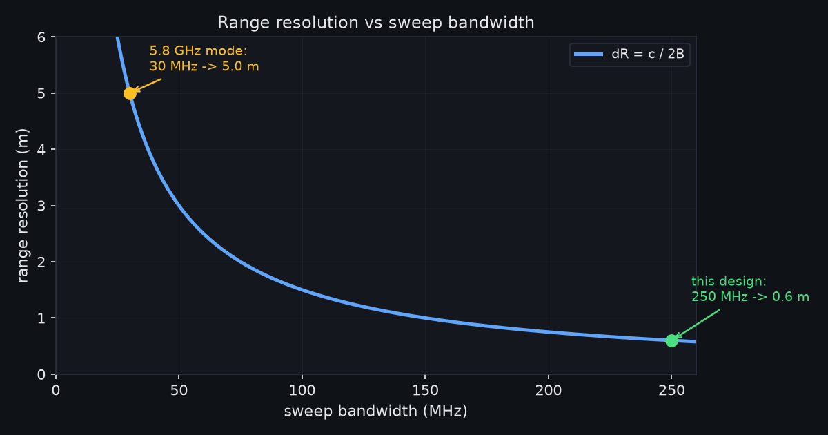
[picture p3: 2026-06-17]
docs/figures/system-design/range_resolution.png

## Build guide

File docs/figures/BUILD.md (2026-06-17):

# Figures

All figures in the design documents are generated from source and committed as
`.svg` (and `.png` for the data plots). The documents reference the `.svg` files;
nothing in the rendered HTML is hand-drawn. This mirrors the PMVB figure pipeline.

## Two kinds of figure

| Kind | Source | Toolchain | Use for |
| --- | --- | --- | --- |
| **TikZ** | `*.tex` | `pdflatex` -> `pdftocairo -svg` | block diagrams, signal-chain schematics, pin maps, timing sketches |
| **Data plot** | `*.py` | Python + matplotlib | computed curves (beat-vs-range, filter response, spectra) |

Pick TikZ when the figure is a *diagram* (boxes, wires, geometry). Pick matplotlib
when the figure is *plotted data* from an equation or a simulation.

## Layout

```
docs/figures/
  build-all.ps1            # builds everything (TikZ + matplotlib)
  BUILD.md                 # this file
  style/
    pmvb-figures.sty       # shared house style: dark theme, node/edge styles
  system-design/           # figures for the System Design Document
    fmcw_chirp_beat.tex    # Fig 5-1  (TikZ)
    beat_vs_range.py       # Fig 5-2  (matplotlib)
    range_resolution.py    # Fig 5-3  (matplotlib)
  rf-frontend/             # (future) RF Front-End Module figures
  baseband/                # (future) I/Q Baseband Board figures
```

Each per-board doc gets its own subdirectory under `docs/figures/`. `build-all.ps1`
discovers them automatically.

## Build

From `docs/figures/`:

```powershell
.\build-all.ps1
```

This compiles every `*.tex` (skipping `style/`) to `.svg` and runs every `*.py`
plot script. It needs `pdflatex` (MiKTeX) and `pdftocairo` (Poppler) on PATH for
TikZ, and Python with `matplotlib` + `numpy` for the plots.

Build a single figure by hand:

```powershell
# TikZ
cd system-design
pdflatex fmcw_chirp_beat.tex
pdftocairo -svg fmcw_chirp_beat.pdf fmcw_chirp_beat.svg

# matplotlib
python beat_vs_range.py
```

## Authoring a new figure

**TikZ.** Start from this preamble; dark mode is applied automatically.

```latex
\documentclass[border=8pt]{standalone}
\input{../style/pmvb-figures.sty}
\begin{document}
\begin{tikzpicture}[pmvb figure]
  % use pmvb subsystem / pmvb ic / pmvb digital / pmvb analog / pmvb power ...
  % colors: pmvbFg pmvbMuted pmvbBlue pmvbGreen pmvbAmber pmvbRed pmvbViolet
\end{tikzpicture}
\end{document}
```

See `system-design/00`-style legends in the PMVB repo for the full box/wire
vocabulary defined in `pmvb-figures.sty`.

**matplotlib.** Copy the palette block from `system-design/beat_vs_range.py`
(`BG / PANEL / FG / MUTED / GRID / BLUE / AMBER / RED / GREEN`), use
`matplotlib.use("Agg")`, and `savefig(..., facecolor=BG)` to both `.svg` and `.png`.

## Referencing figures in a document

Reference the compiled `.svg` with a relative path from the document, wrapped in a
`<figure>` so the SDD theme styles the caption:

```html
<figure>
<img src="../figures/system-design/beat_vs_range.svg" alt="Beat frequency vs range">
<figcaption><strong>Figure 5-2.</strong> Beat frequency versus target range ...</figcaption>
</figure>
```

Always rebuild figures before rendering the document, so the `.svg` files are current.

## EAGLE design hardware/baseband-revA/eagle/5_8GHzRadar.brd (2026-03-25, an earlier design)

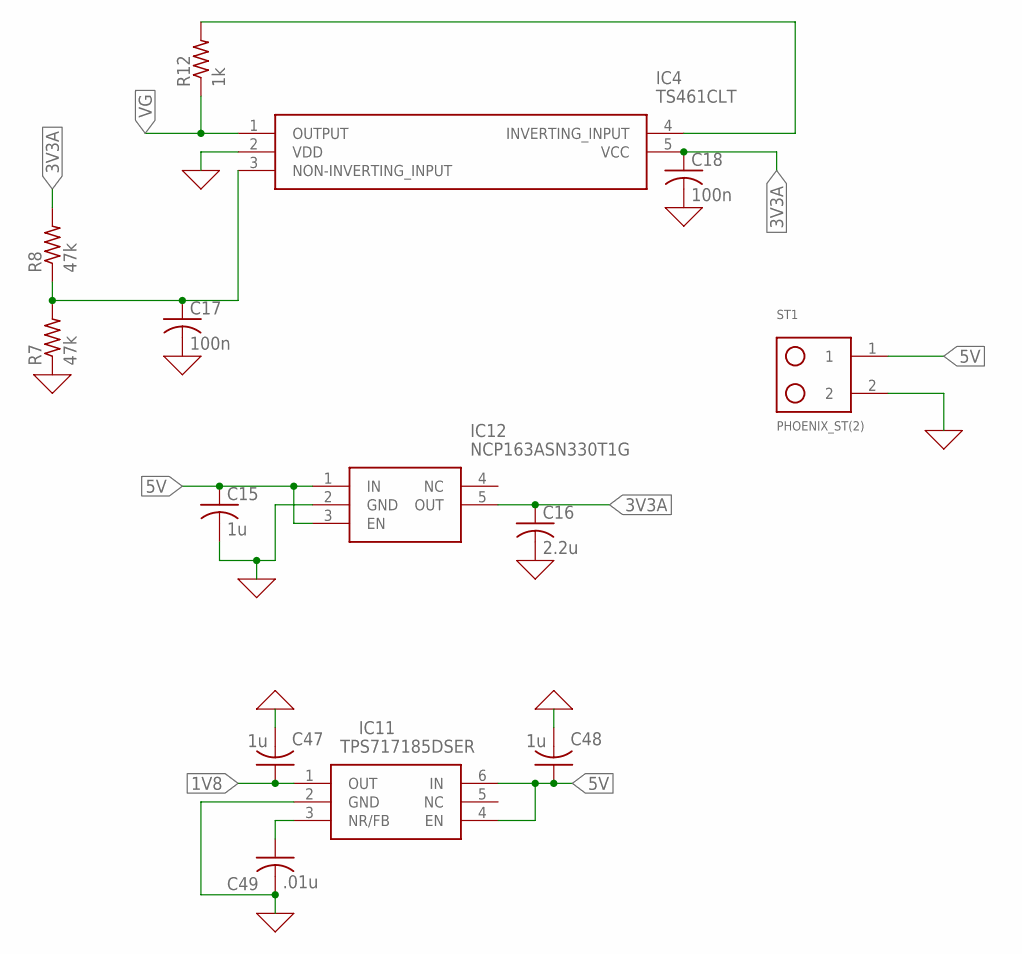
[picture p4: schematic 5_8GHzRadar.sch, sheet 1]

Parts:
C15, C47, C48: 1u; C0805
C16: 2.2u; C0805
C17, C18: 100n; C0805
C49: .01u; C0805
IC4: TS461CLT; SOT95P280X145-5N@1
IC11: TPS717185DSER; SON50P150X150X80-6N
IC12: NCP163ASN330T1G; SOT95P280X145-5N
R7, R8: 47k; R0805
R12: 1k; R0805
ST1: PHOENIX_ST(2); PHEONIX_SCREW(2)

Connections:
0: C15.2, C16.2, C17.2, C18.2, C47.2, C48.2, C49.2, IC4.2 (VDD), IC11.2 (GND), IC12.2 (GND), R7.1, ST1.2; also elsewhere on the board
1V8: C47.1, IC11.1 (OUT); also elsewhere on the board
3V3A: C16.1, C18.1, IC4.5 (VCC), IC12.5 (OUT), R8.2; also elsewhere on the board
5V: C15.1, C48.1, IC11.4 (EN), IC11.6 (IN), IC12.1 (IN), IC12.3 (EN), ST1.1; also elsewhere on the board
unnamed: C17.1, IC4.3 (NON-INVERTING_INPUT), R7.2, R8.1
unnamed: IC4.4 (INVERTING_INPUT), R12.2
unnamed: C49.1, IC11.3 (NR/FB)
VG: IC4.1 (OUTPUT), R12.1; also elsewhere on the board

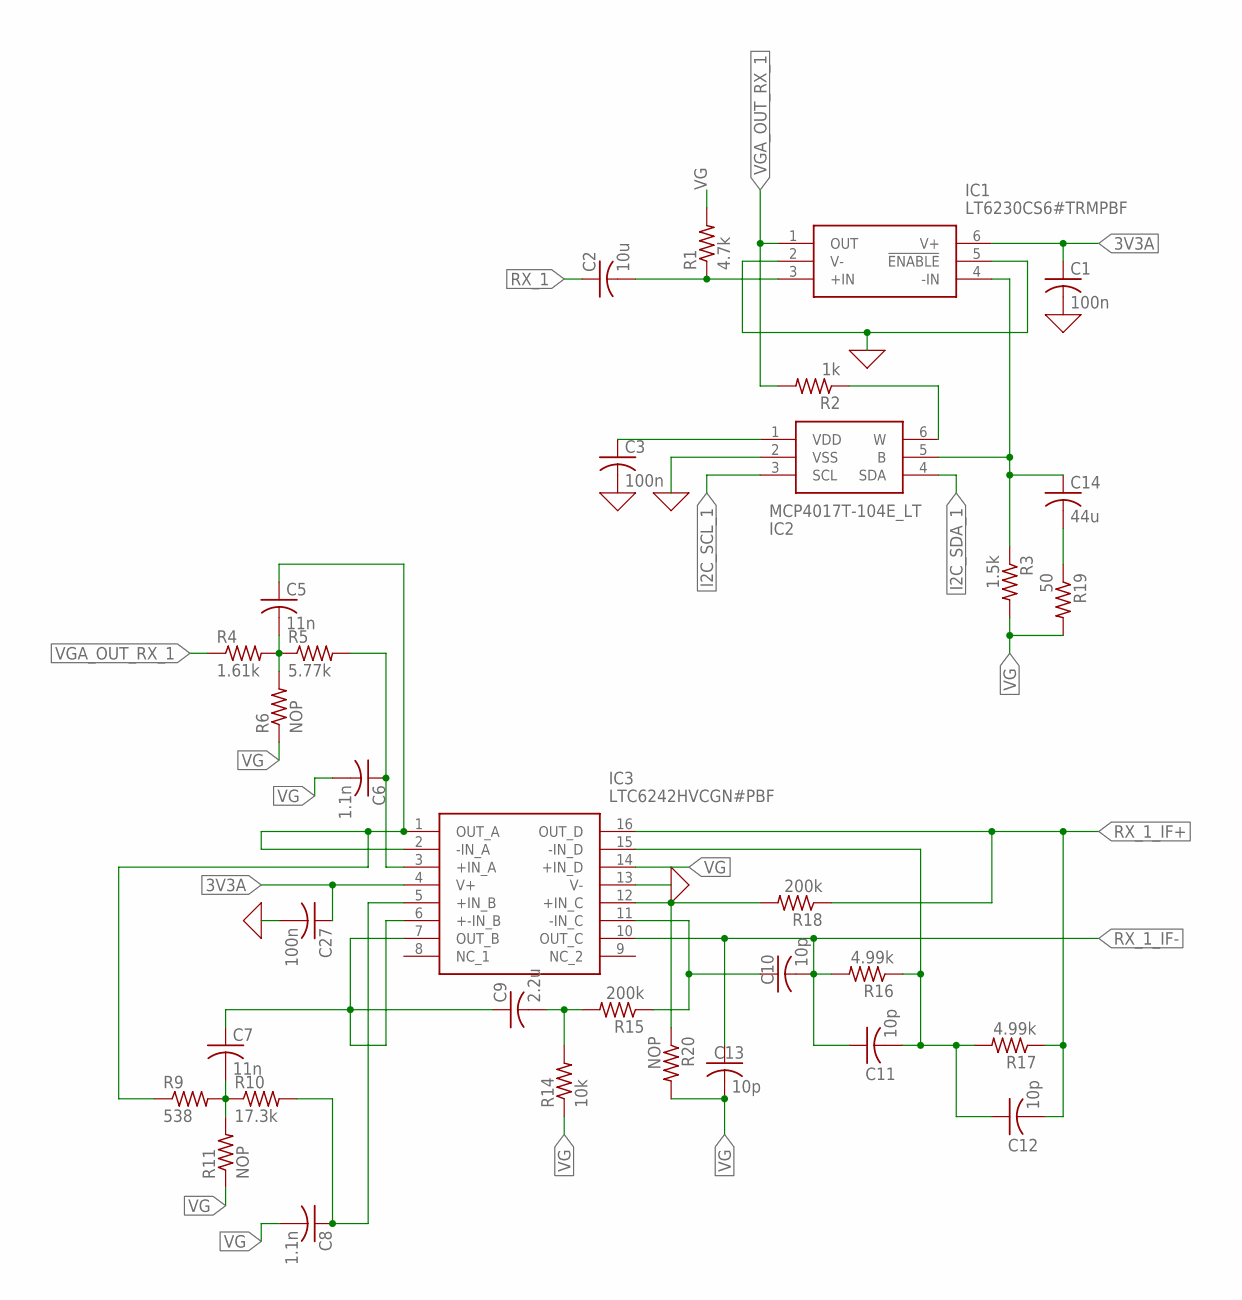
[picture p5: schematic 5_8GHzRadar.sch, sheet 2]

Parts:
C1, C3, C27: 100n; C0805
C2: 10u; C0805
C5, C7: 11n; C0805
C6, C8: 1.1n; C0805
C9: 2.2u; C0805
C10, C11, C12, C13: 10p; C0805
C14: 44u; C0603
IC1: LT6230CS6#TRMPBF; SOT95P280X100-6N
IC2: MCP4017T-104E_LT; SOT65P210X110-6N
IC3: LTC6242HVCGN#PBF; SOP64P601X175-16N
R1: 4.7k; R0805
R2: 1k; R0805
R3: 1.5k; R0805
R4: 1.61k; R0805
R5: 5.77k; R0805
R6, R11, R20: NOP; R0805
R9: 538; R0805
R10: 17.3k; R0805
R14: 10k; R0805
R15, R18: 200k; R0805
R16, R17: 4.99k; R0805
R19: 50; R0805

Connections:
0: C1.2, C3.2, C27.2, IC1.2 (V-), IC1.5 (!ENABLE), IC2.2 (VSS), IC3.13 (V-); also elsewhere on the board
3V3A: C1.1, C27.1, IC1.6 (V+), IC3.4 (V+); also elsewhere on the board
FILTER1: C5.1, IC3.1 (OUT_A), IC3.2 (-IN_A), R9.1
I2C_SCL_1: IC2.3 (SCL); also elsewhere on the board
I2C_SDA_1: IC2.4 (SDA); also elsewhere on the board
unnamed: C14.1, IC1.4 (-IN), IC2.5 (B), R3.1
unnamed: C2.2, IC1.3 (+IN), R1.1
unnamed: C5.2, R4.2, R5.1, R6.2
unnamed: IC2.6 (W), R2.1
unnamed: C3.1, IC2.1 (VDD)
unnamed: C9.2, R14.2, R15.2
unnamed: C6.1, IC3.3 (+IN_A), R5.2
unnamed: C7.2, R9.2, R10.1, R11.2
unnamed: C8.1, IC3.5 (+IN_B), R10.2
unnamed: C7.1, C9.1, IC3.6 (+-IN_B), IC3.7 (OUT_B)
unnamed: C10.1, IC3.11 (-IN_C), R15.1
unnamed: C14.2, R19.1
unnamed: IC3.12 (+IN_C), R18.2, R20.1
unnamed: C11.2, C12.1, IC3.15 (-IN_D), R16.1, R17.2
RX_1: C2.1; also elsewhere on the board
RX_1_IF+: C12.2, IC3.16 (OUT_D), R17.1, R18.1; also elsewhere on the board
RX_1_IF-: C10.2, C11.1, C13.1, IC3.10 (OUT_C), R16.2; also elsewhere on the board
VG: C6.2, C8.2, C13.2, IC3.14 (+IN_D), R1.2, R3.2, R6.1, R11.1, R14.1, R19.2, R20.2; also elsewhere on the board
VGA_OUT_RX_1: IC1.1 (OUT), R2.2, R4.1

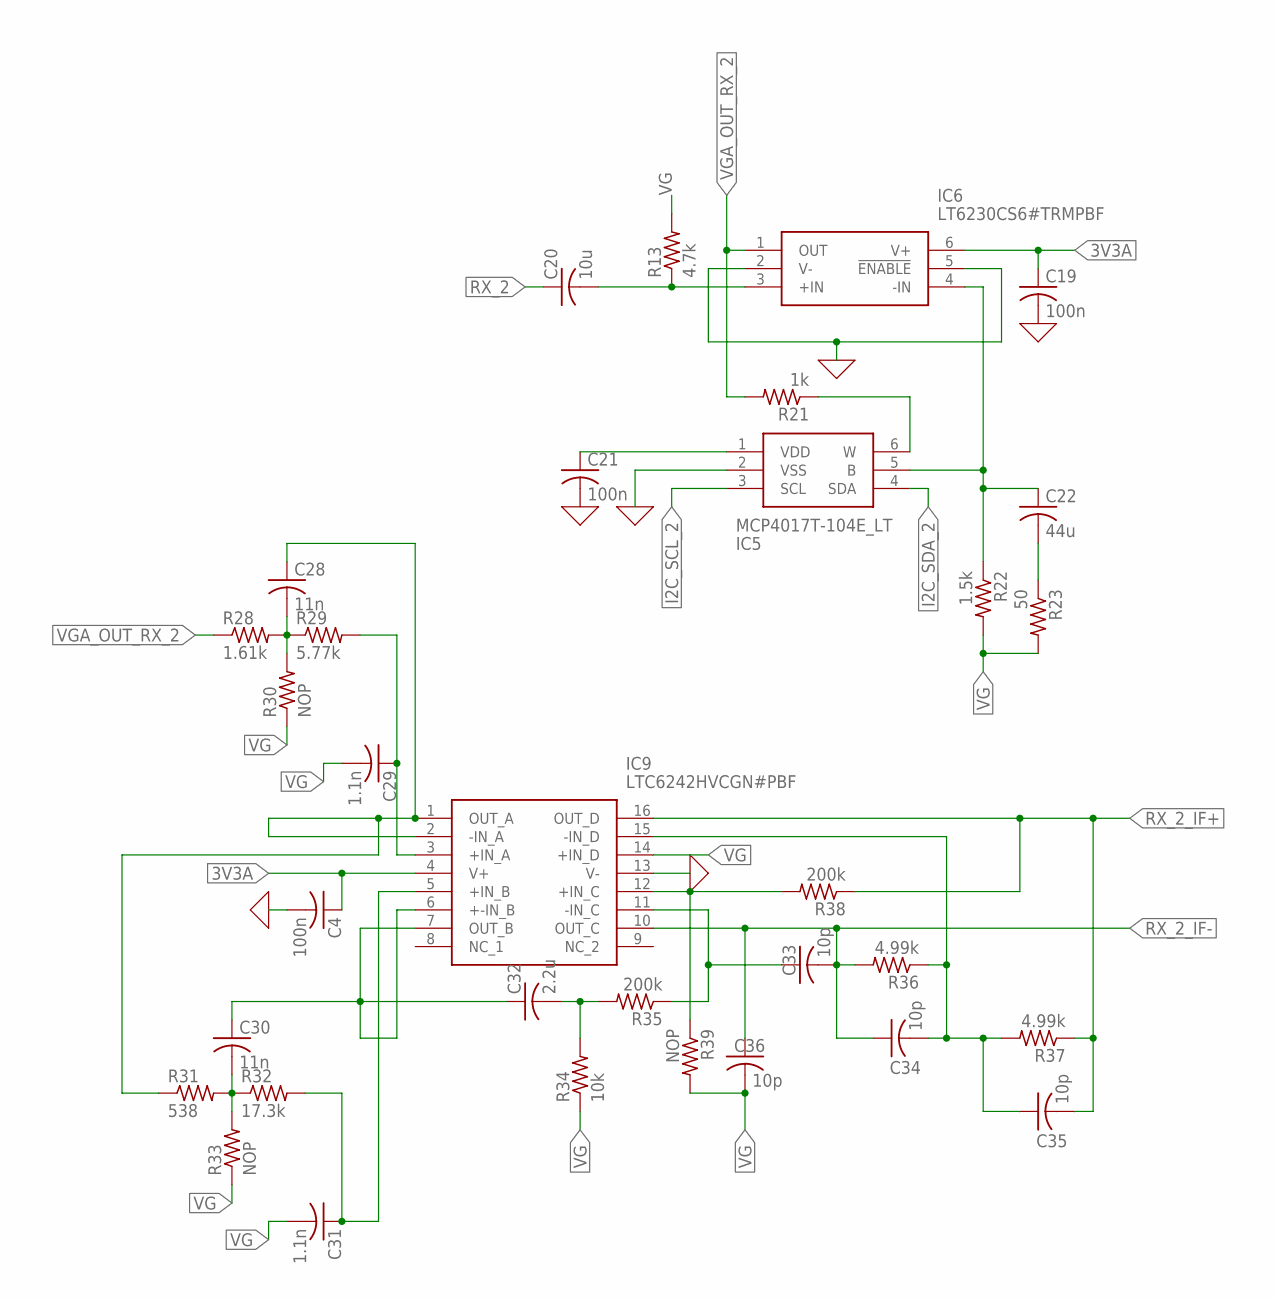
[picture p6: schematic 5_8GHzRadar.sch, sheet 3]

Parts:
C4, C19, C21: 100n; C0805
C20: 10u; C0805
C22: 44u; C0805
C28, C30: 11n; C0805
C29, C31: 1.1n; C0805
C32: 2.2u; C0805
C33, C34, C35, C36: 10p; C0805
IC5: MCP4017T-104E_LT; SOT65P210X110-6N
IC6: LT6230CS6#TRMPBF; SOT95P280X100-6N
IC9: LTC6242HVCGN#PBF; SOP64P601X175-16N
R13: 4.7k; R0805
R21: 1k; R0805
R22: 1.5k; R0805
R23: 50; R0805
R28: 1.61k; R0805
R29: 5.77k; R0805
R30, R33, R39: NOP; R0805
R31: 538; R0805
R32: 17.3k; R0805
R34: 10k; R0805
R35, R38: 200k; R0805
R36, R37: 4.99k; R0805

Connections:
0: C4.2, C19.2, C21.2, IC5.2 (VSS), IC6.2 (V-), IC6.5 (!ENABLE), IC9.13 (V-); also elsewhere on the board
3V3A: C4.1, C19.1, IC6.6 (V+), IC9.4 (V+); also elsewhere on the board
FILTER2: C28.1, IC9.1 (OUT_A), IC9.2 (-IN_A), R31.1
I2C_SCL_2: IC5.3 (SCL); also elsewhere on the board
I2C_SDA_2: IC5.4 (SDA); also elsewhere on the board
unnamed: C22.1, IC5.5 (B), IC6.4 (-IN), R22.1
unnamed: C20.2, IC6.3 (+IN), R13.1
unnamed: IC5.6 (W), R21.1
unnamed: C21.1, IC5.1 (VDD)
unnamed: C22.2, R23.1
unnamed: C28.2, R28.2, R29.1, R30.2
unnamed: C29.1, IC9.3 (+IN_A), R29.2
unnamed: C30.2, R31.2, R32.1, R33.2
unnamed: C31.1, IC9.5 (+IN_B), R32.2
unnamed: C30.1, C32.1, IC9.6 (+-IN_B), IC9.7 (OUT_B)
unnamed: C32.2, R34.2, R35.2
unnamed: C33.1, IC9.11 (-IN_C), R35.1
unnamed: C34.2, C35.1, IC9.15 (-IN_D), R36.1, R37.2
unnamed: IC9.12 (+IN_C), R38.2, R39.1
RX_2: C20.1; also elsewhere on the board
RX_2_IF+: C35.2, IC9.16 (OUT_D), R37.1, R38.1; also elsewhere on the board
RX_2_IF-: C33.2, C34.1, C36.1, IC9.10 (OUT_C), R36.2; also elsewhere on the board
VG: C29.2, C31.2, C36.2, IC9.14 (+IN_D), R13.2, R22.2, R23.2, R30.1, R33.1, R34.1, R39.2; also elsewhere on the board
VGA_OUT_RX_2: IC6.1 (OUT), R21.2, R28.1

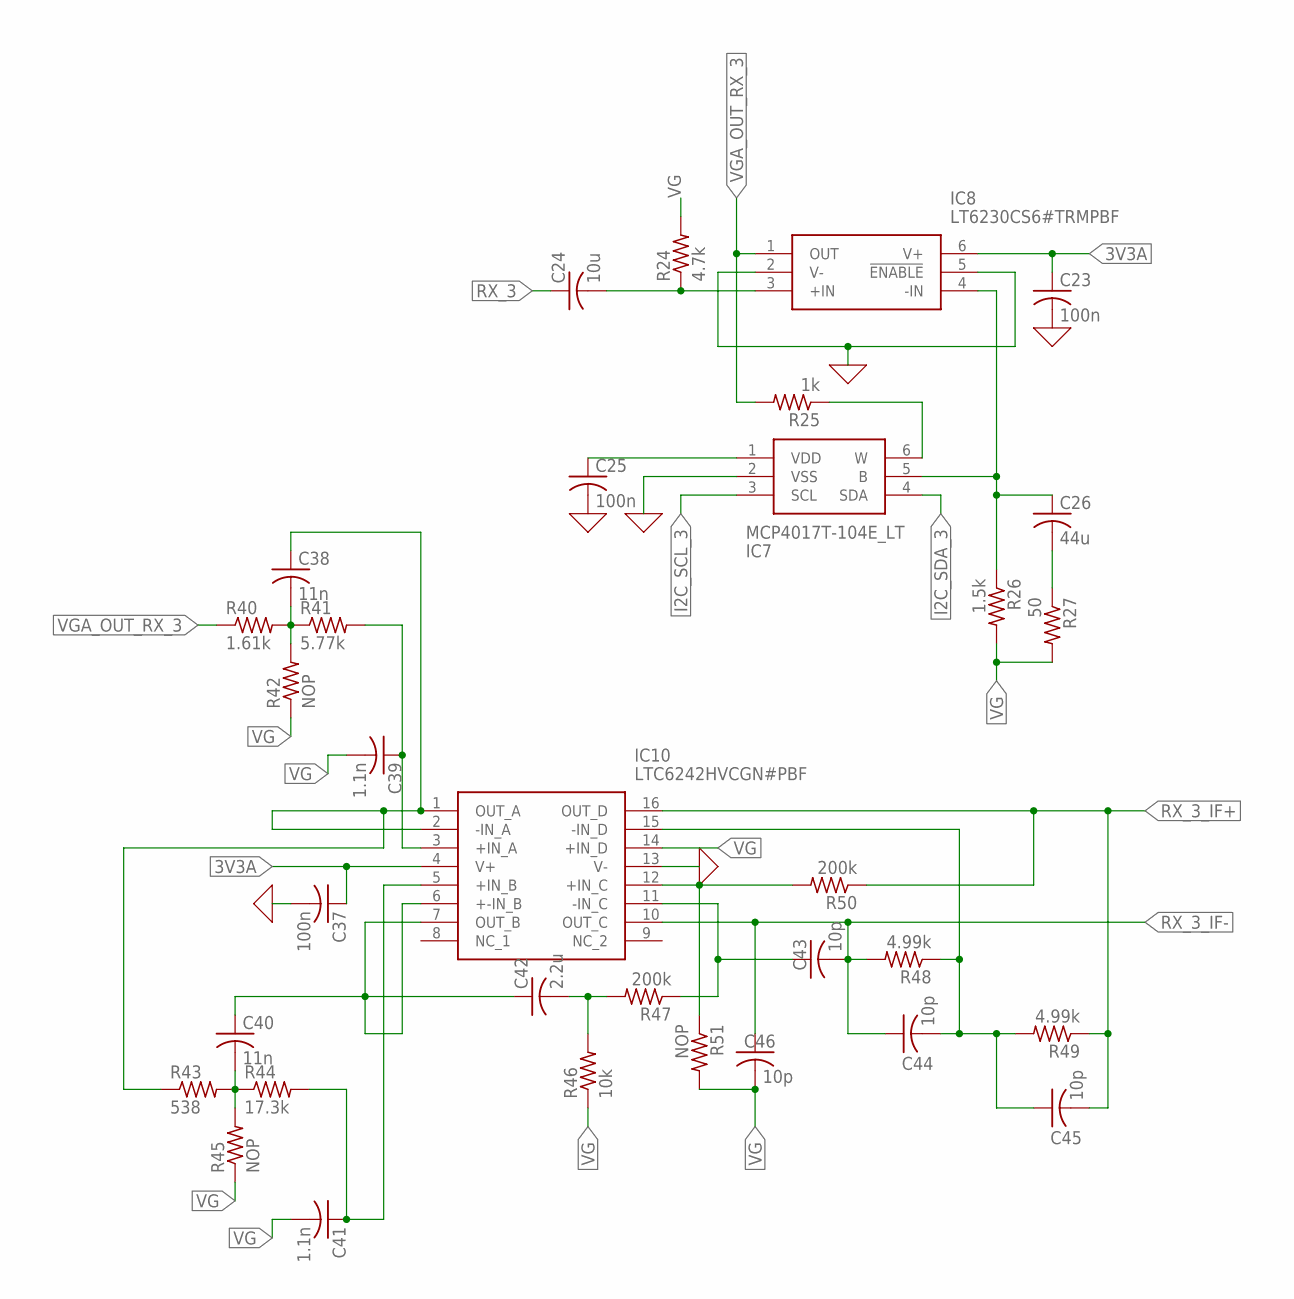
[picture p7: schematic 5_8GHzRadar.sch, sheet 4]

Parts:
C23, C25, C37: 100n; C0805
C24: 10u; C0805
C26: 44u; C0805
C38, C40: 11n; C0805
C39, C41: 1.1n; C0805
C42: 2.2u; C0805
C43, C44, C45, C46: 10p; C0805
IC7: MCP4017T-104E_LT; SOT65P210X110-6N
IC8: LT6230CS6#TRMPBF; SOT95P280X100-6N
IC10: LTC6242HVCGN#PBF; SOP64P601X175-16N
R24: 4.7k; R0805
R25: 1k; R0805
R26: 1.5k; R0805
R27: 50; R0805
R40: 1.61k; R0805
R41: 5.77k; R0805
R42, R45, R51: NOP; R0805
R43: 538; R0805
R44: 17.3k; R0805
R46: 10k; R0805
R47, R50: 200k; R0805
R48, R49: 4.99k; R0805

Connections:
0: C23.2, C25.2, C37.2, IC7.2 (VSS), IC8.2 (V-), IC8.5 (!ENABLE), IC10.13 (V-); also elsewhere on the board
3V3A: C23.1, C37.1, IC8.6 (V+), IC10.4 (V+); also elsewhere on the board
FILTER3: C38.1, IC10.1 (OUT_A), IC10.2 (-IN_A), R43.1
I2C_SCL_3: IC7.3 (SCL); also elsewhere on the board
I2C_SDA_3: IC7.4 (SDA); also elsewhere on the board
unnamed: C26.1, IC7.5 (B), IC8.4 (-IN), R26.1
unnamed: C24.2, IC8.3 (+IN), R24.1
unnamed: IC7.6 (W), R25.1
unnamed: C25.1, IC7.1 (VDD)
unnamed: C26.2, R27.1
unnamed: C38.2, R40.2, R41.1, R42.2
unnamed: C39.1, IC10.3 (+IN_A), R41.2
unnamed: C40.2, R43.2, R44.1, R45.2
unnamed: C41.1, IC10.5 (+IN_B), R44.2
unnamed: C40.1, C42.1, IC10.6 (+-IN_B), IC10.7 (OUT_B)
unnamed: C42.2, R46.2, R47.2
unnamed: C43.1, IC10.11 (-IN_C), R47.1
unnamed: C44.2, C45.1, IC10.15 (-IN_D), R48.1, R49.2
unnamed: IC10.12 (+IN_C), R50.2, R51.1
RX_3: C24.1; also elsewhere on the board
RX_3_IF+: C45.2, IC10.16 (OUT_D), R49.1, R50.1; also elsewhere on the board
RX_3_IF-: C43.2, C44.1, C46.1, IC10.10 (OUT_C), R48.2; also elsewhere on the board
VG: C39.2, C41.2, C46.2, IC10.14 (+IN_D), R24.2, R26.2, R27.2, R42.1, R45.1, R46.1, R51.2; also elsewhere on the board
VGA_OUT_RX_3: IC8.1 (OUT), R25.2, R40.1

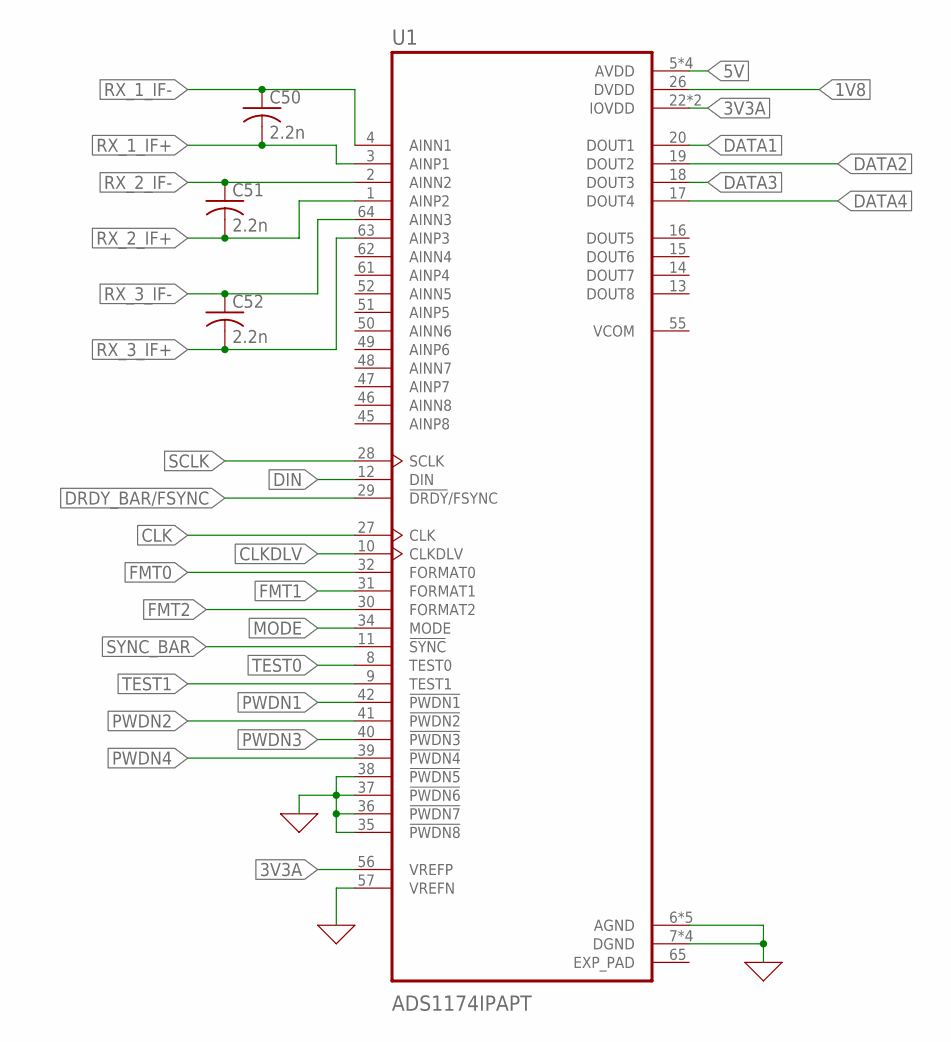
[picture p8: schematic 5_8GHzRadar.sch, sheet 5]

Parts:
C50, C51, C52: 2.2n; C0805
U1: ADS1174IPAPT; QFP50P1200X1200X120-65N

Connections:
0: U1.6 (AGND), U1.7 (DGND), U1.21 (DGND), U1.24 (DGND), U1.25 (DGND), U1.35 (!PWDN8), U1.36 (!PWDN7), U1.37 (!PWDN6), U1.38 (!PWDN5), U1.43 (AGND), U1.54 (AGND), U1.57 (VREFN), U1.58 (AGND), U1.59 (AGND); also elsewhere on the board
1V8: U1.26 (DVDD); also elsewhere on the board
3V3A: U1.22 (IOVDD), U1.23 (IOVDD), U1.56 (VREFP); also elsewhere on the board
5V: U1.5 (AVDD), U1.44 (AVDD), U1.53 (AVDD), U1.60 (AVDD); also elsewhere on the board
CLK: U1.27 (CLK); also elsewhere on the board
CLKDLV: U1.10 (CLKDLV); also elsewhere on the board
DATA1: U1.20 (DOUT1); also elsewhere on the board
DATA2: U1.19 (DOUT2); also elsewhere on the board
DATA3: U1.18 (DOUT3); also elsewhere on the board
DATA4: U1.17 (DOUT4); also elsewhere on the board
DIN: U1.12 (DIN); also elsewhere on the board
DRDY_BAR/FSYNC: U1.29 (!DRDY!/FSYNC); also elsewhere on the board
EXP_PAD: U1.65 (EXP_PAD)
FMT0: U1.32 (FORMAT0); also elsewhere on the board
FMT1: U1.31 (FORMAT1); also elsewhere on the board
FMT2: U1.30 (FORMAT2); also elsewhere on the board
MODE: U1.34 (MODE); also elsewhere on the board
PWDN1: U1.42 (!PWDN1); also elsewhere on the board
PWDN2: U1.41 (!PWDN2); also elsewhere on the board
PWDN3: U1.40 (!PWDN3); also elsewhere on the board
PWDN4: U1.39 (!PWDN4); also elsewhere on the board
RX_1_IF+: C50.2, U1.3 (AINP1); also elsewhere on the board
RX_1_IF-: C50.1, U1.4 (AINN1); also elsewhere on the board
RX_2_IF+: C51.2, U1.1 (AINP2); also elsewhere on the board
RX_2_IF-: C51.1, U1.2 (AINN2); also elsewhere on the board
RX_3_IF+: C52.2, U1.63 (AINP3); also elsewhere on the board
RX_3_IF-: C52.1, U1.64 (AINN3); also elsewhere on the board
SCLK: U1.28 (SCLK); also elsewhere on the board
SYNC_BAR: U1.11 (!SYNC); also elsewhere on the board
TEST0: U1.8 (TEST0); also elsewhere on the board
TEST1: U1.9 (TEST1); also elsewhere on the board

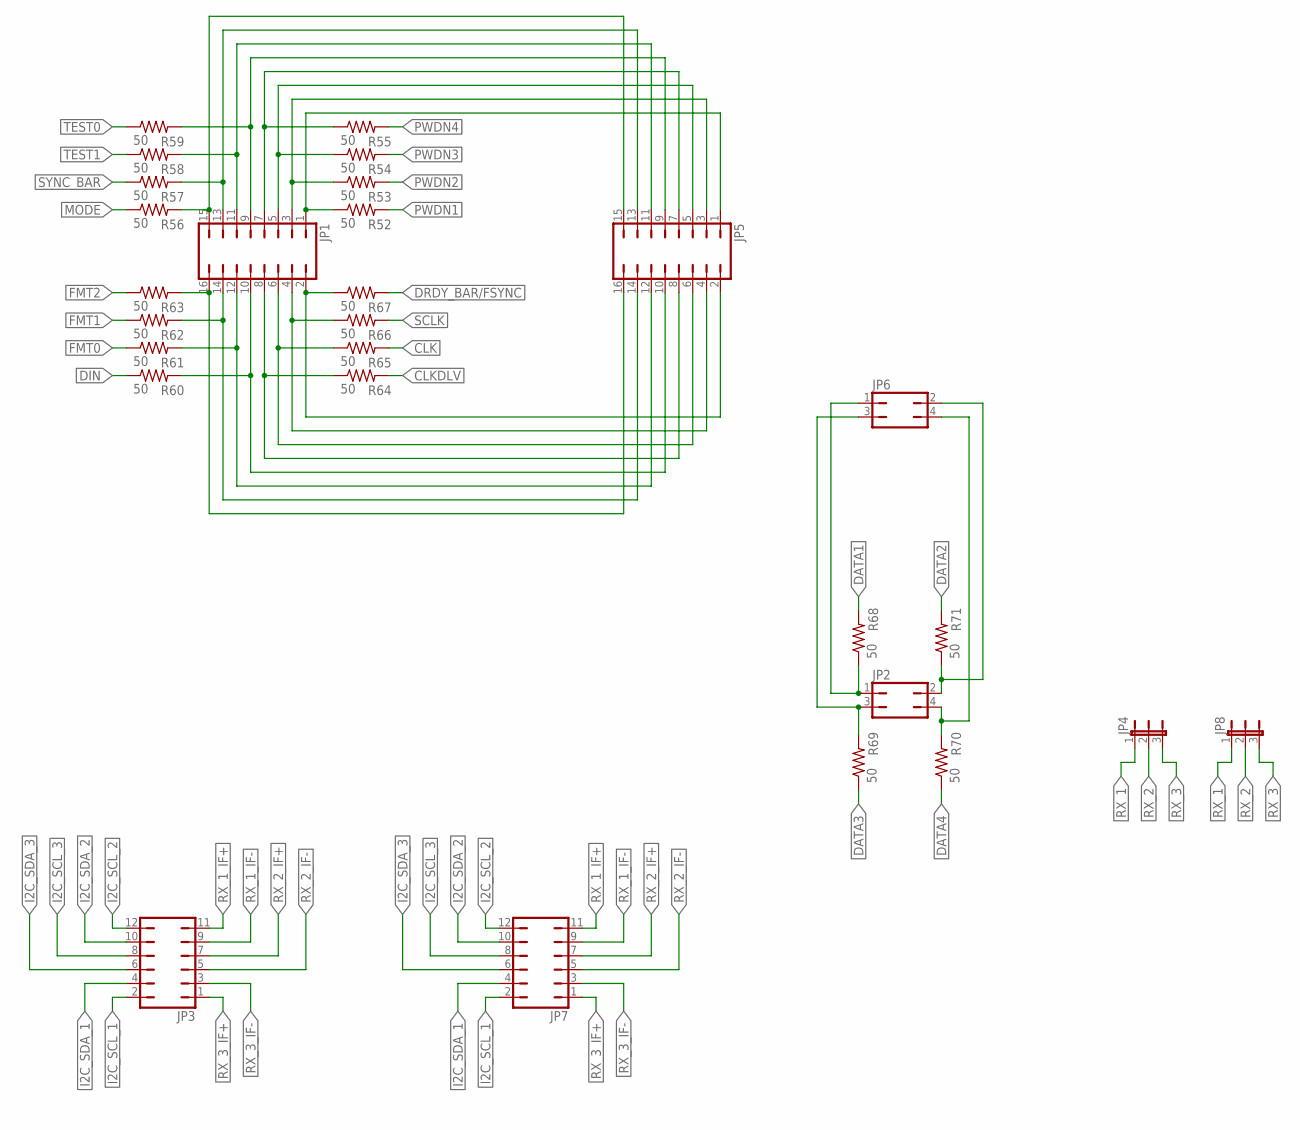
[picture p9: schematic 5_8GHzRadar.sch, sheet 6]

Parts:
JP1, JP5: JP8Q
JP2, JP6: JP2Q
JP3, JP7: JP6Q
JP4, JP8: JP2E; JP2
R52, R53, R54, R55, R56, R57, R58, R59, R60, R61, R62, R63, R64, R65, R66, R67, R68, R69, R70, R71: 50; R0805

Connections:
CLK: R65.2; also elsewhere on the board
CLKDLV: R64.2; also elsewhere on the board
DATA1: R68.2; also elsewhere on the board
DATA2: R71.2; also elsewhere on the board
DATA3: R69.1; also elsewhere on the board
DATA4: R70.1; also elsewhere on the board
DIN: R60.1; also elsewhere on the board
DRDY_BAR/FSYNC: R67.2; also elsewhere on the board
FMT0: R61.1; also elsewhere on the board
FMT1: R62.1; also elsewhere on the board
FMT2: R63.1; also elsewhere on the board
I2C_SCL_1: JP3.2, JP7.2; also elsewhere on the board
I2C_SCL_2: JP3.12, JP7.12; also elsewhere on the board
I2C_SCL_3: JP3.8, JP7.8; also elsewhere on the board
I2C_SDA_1: JP3.4, JP7.4; also elsewhere on the board
I2C_SDA_2: JP3.10, JP7.10; also elsewhere on the board
I2C_SDA_3: JP3.6, JP7.6; also elsewhere on the board
MODE: R56.1; also elsewhere on the board
unnamed: JP1.1, JP5.1, R52.1
unnamed: JP1.3, JP5.3, R53.1
unnamed: JP1.5, JP5.5, R54.1
unnamed: JP1.7, JP5.7, R55.1
unnamed: JP1.9, JP5.9, R59.2
unnamed: JP1.15, JP5.15, R56.2
unnamed: JP1.13, JP5.13, R57.2
unnamed: JP1.11, JP5.11, R58.2
unnamed: JP1.16, JP5.16, R63.2
unnamed: JP1.10, JP5.10, R60.2
unnamed: JP1.12, JP5.12, R61.2
unnamed: JP1.14, JP5.14, R62.2
unnamed: JP1.8, JP5.8, R64.1
unnamed: JP1.6, JP5.6, R65.1
unnamed: JP1.4, JP5.4, R66.1
unnamed: JP1.2, JP5.2, R67.1
unnamed: JP2.1, JP6.1, R68.1
unnamed: JP2.3, JP6.3, R69.2
unnamed: JP2.4, JP6.4, R70.2
unnamed: JP2.2, JP6.2, R71.1
PWDN1: R52.2; also elsewhere on the board
PWDN2: R53.2; also elsewhere on the board
PWDN3: R54.2; also elsewhere on the board
PWDN4: R55.2; also elsewhere on the board
RX_1: JP4.1, JP8.1; also elsewhere on the board
RX_1_IF+: JP3.11, JP7.11; also elsewhere on the board
RX_1_IF-: JP3.9, JP7.9; also elsewhere on the board
RX_2: JP4.2, JP8.2; also elsewhere on the board
RX_2_IF+: JP3.7, JP7.7; also elsewhere on the board
RX_2_IF-: JP3.5, JP7.5; also elsewhere on the board
RX_3: JP4.3, JP8.3; also elsewhere on the board
RX_3_IF+: JP3.1, JP7.1; also elsewhere on the board
RX_3_IF-: JP3.3, JP7.3; also elsewhere on the board
SCLK: R66.2; also elsewhere on the board
SYNC_BAR: R57.1; also elsewhere on the board
TEST0: R59.1; also elsewhere on the board
TEST1: R58.1; also elsewhere on the board

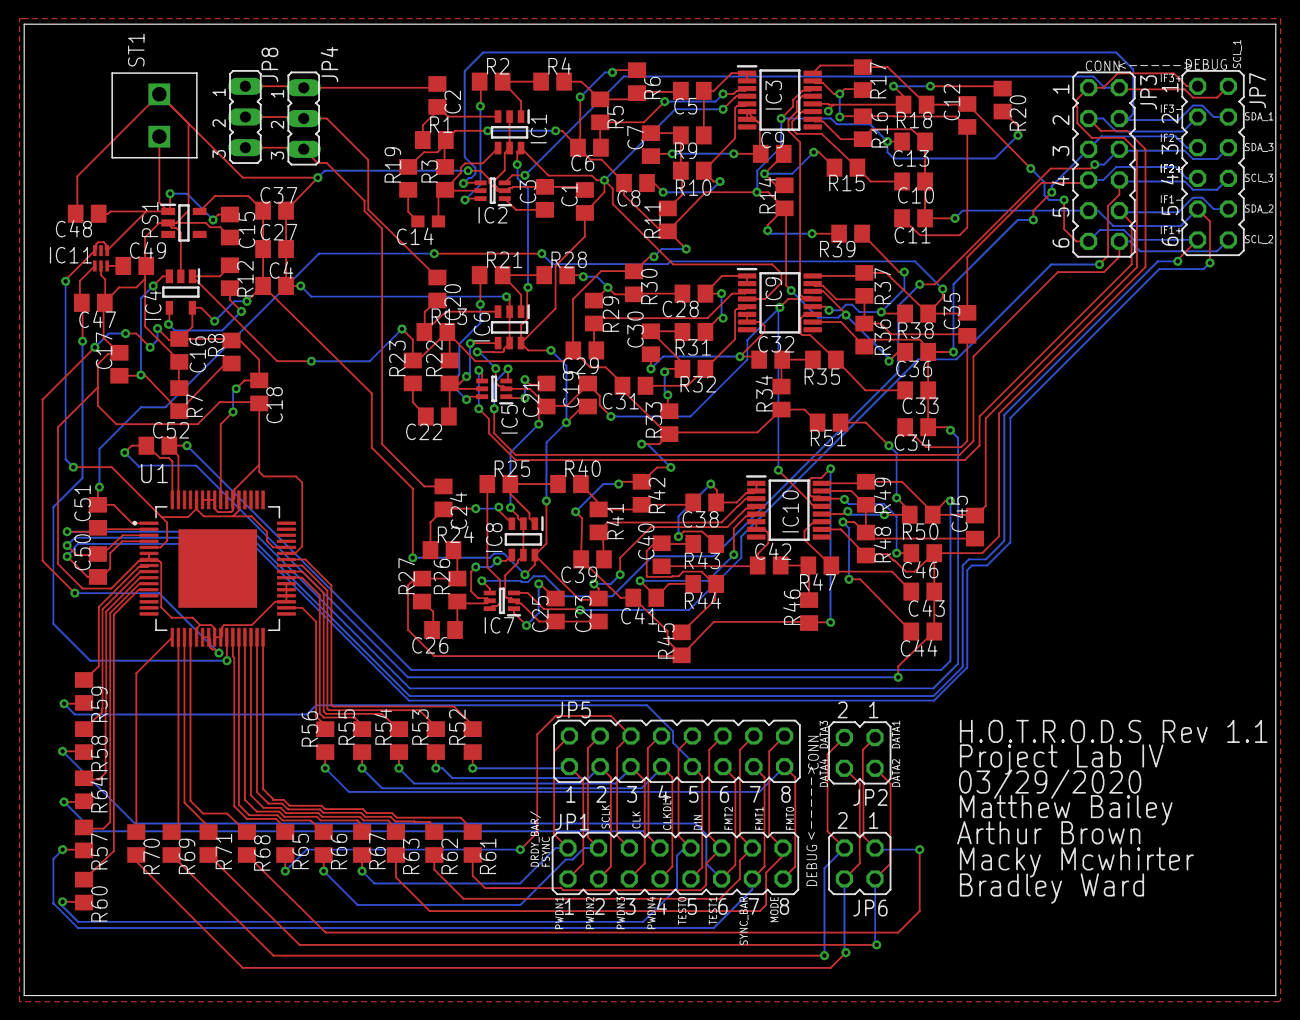
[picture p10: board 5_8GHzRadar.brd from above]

Board: 2 copper layers, 103.5 x 80.3 mm, 145 parts (0 on the bottom side), 111 nets.

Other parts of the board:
PS1: TPS70918DBVT; SOT95P280X145-5N

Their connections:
0: PS1.2; also elsewhere on the board
3V3A: PS1.5; also elsewhere on the board
5V: PS1.1; also elsewhere on the board

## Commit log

2026-03-25 Initial commit: FMCW radar baseband Rev B schematic and documentation
    [5_8GHzRadar.brd, 5_8GHzRadar.sch, Baseband PCB.kicad_pcb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]
2026-03-27 Update FPGA targets: Tang Nano 9K for radar, Tang Primer 25K in hand for RISC, Phase 2 high-speed boards
2026-03-27 Complete design rationale: add §4 Sheet B, §5 Sheet C, §6 Sheet D - §4: ESD protection, AC coupling (f_HP=33.9Hz), DC bias (47k to VCM) - §5: PGA113 variable gain (1-200x), 4th-order Sallen-Key Butte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
2026-03-27 Add §3.1.3 capacitor placement analysis with trace impedance chart
    - Derive placement rules from trace inductance (1 nH/mm) vs cap impedance
    - SVG impedance chart: 100nF at 1mm/2mm/5mm/10mm trace lengths
    - Worked example: 10mm trace adds 3.3 ohm at 50 MHz (100x cap impedance)
    - Placement rules table: 100nF ≤2mm, 1uF ≤5mm, 10uF ≤10mm
    - Interview-ready summary for capacitor placement rationale
2026-03-27 Add missing figure/table captions: §1.6 radar path, §2.2a signal flow, §3.1 power chain
    - 9 figures and 38 tables now captioned with centered italic labels
    - Table of Figures updated to 8 entries with correct anchor links
    - Fixed duplicate table caption on §2.2 component map
2026-03-27 Integrate all block diagrams into system design document
    - Fig 2.2b: top-level 4-sheet hierarchy with inter-sheet signal routing
    - Fig 3.1b: Sheet A detailed power/reference block diagram
    - Fig 4.1b: Sheet B component-level signal path diagram
    - Fig 6.1b: Sheet D FDA/ADC/J_DFT block diagram with SPI routing
    - Fig 5.1b: Sheet C block diagram (already integrated last commit)
    - Table of Figures updated to 14 entries
    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
2026-03-28 Add schematic and PCB layout change plans, consolidate README status
    - Schematic_Updates_Change_Plan.docx: 9 CRs (SCH-01 to SCH-09)
    Filter wiring fixes, ERC resolution, FPGA connector, schematic freeze
    - PCB_Layout_Change_Plan.docx: 8 tasks (PCB-01 to PCB-08)
    4-layer stackup, placement, ground strategy, routing, DRC
    - README status: consolidated design rationale into single checkbox
    with sub-items, added sub-checkboxes for all SCH and PCB tasks
2026-03-28 Update README with task progress and schematic updates
    Removed completed tasks and updated schematic change plan.
2026-03-28 Schematic audit: correct C14 floating (not grounded), add SCH-00 prerequisite
    Programmatic audit of KiCad schematic found:
    - Zero GND power symbols on Sheet C (new SCH-00 prerequisite)
    - C14 is FLOATING, not grounded as originally reported
    - 7 isolated net labels (placed but not connected to any wire)
    - LTC6242 signal pins entirely unreachable from wire network
    - PGA113 wiring is correct; Sheets A, B, D substantially complete
    Updated: Schematic Change Plan, System Design Document §5.4,
    Filter Analysis §3 diagnosis, README checklist
2026-03-28 Add KiCad SVG schematic exports for all sheets and annotated audit
    - Root_Hierarchy.svg: top-level sheet hierarchy
    - Sheet_A_Power_Refs.svg: power and references
    - Sheet_B_IF_Input.svg: IF input, protection, bias
    - Sheet_C_PGA_Filter.svg: PGA and anti-alias filter
    - Sheet_D_FDA_ADC_SPI.svg: FDA, ADC, SPI interface
    - Sheet_C_Annotated_Audit.svg: Sheet C with issue annotations
2026-03-28 Add KiCad schematic SVG exports and updated annotated audit
    - Root_Hierarchy.svg: top-level hierarchical sheet view
    - Sheet_A_Power_Refs.svg: power rail and reference generation
    - Sheet_B_IF_Input.svg: IF input with ESD, AC coupling, DC bias
    - Sheet_C_PGA_Filter.svg: PGA113 and Sallen-Key filter (pre-fix)
    - Sheet_D_FDA_ADC_SPI.svg: THS4531A FDA, ADS8881 ADC, SPI/DFT
    - Sheet_C_Annotated_Audit.svg: color-coded audit overlay
    - Red: floating filter cap pins (C13-C16 Pin 2)
    - Orange: 7 isolated net labels (no wire connections)
    - Cyan: missing unity-gain feedback wires
    - Green: PGA113 wiring verified correct
    - Updated circle positions for C13.P2 and C15.P2
2026-03-28 Rename KiCad SVG exports and integrate into SDD
    Schematic exports renamed from KiCad defaults to clean names:
    - Baseband PCB.svg → Root_Hierarchy.svg
    - Baseband PCB-Baseband_Power_Refs.svg → Sheet_A_Power_Refs.svg
    - Baseband PCB-Baseband_IF_Input_Protection_Bias.svg → Sheet_B_IF_Input.svg
    - Baseband PCB-Baseband_PGA_AntiAlias.svg → Sheet_C_PGA_Filter.svg
    - Baseband PCB-Baseband_FDA_Driver_ADC_SPI_Interface.svg → Sheet_D_FDA_ADC_SPI.svg
    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
2026-03-28 Integrate KiCad schematic SVGs into System Design Document
    - Add .sch-wrap CSS class for white-background schematic containers
    - Add 'KiCad Schematics' sub-section to Table of Figures (6 entries)
    - Embed 6 SVGs via <img> in collapsible <details> wrappers:
    Fig 2.2c Root Hierarchy, Fig 3.1c Sheet A, Fig 4.1c Sheet B,
    Fig 5.1c Sheet C, Fig 5.4c Sheet C Annotated Audit, Fig 6.1c Sheet D
    - Sheet C annotated audit (Fig 5.4c) expanded by default
    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
2026-03-28 Add filter analysis, system parameter chain, power/IO specs to SDD
    §2.4 Signal Budget replaced with cascaded system parameter chain:
    - Derivation chain from radar equation → ADC → filter → gain/bias
    - Chirp rate / sample rate / FFT coupling callout (Rev A vs Rev B)
    - Power supply rail specs: 5V input, 3V3A, 3V3D, VCM, VREF
    - Current budget: 12.8 mA typ / 17.5 mA max on 3V3A
    - I/O pin voltage specs for all analog, SPI, and reference pins
    §5.4 Anti-Alias Filter expanded with full frequency-domain analysis:
    - Transfer function derivation from node analysis
    - Correct topology: C_shunt(1.1nF) at +IN, C_fb(11nF) at junction
    - Per-stage verification: f0=14,978 Hz, Q=1.309/0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
2026-03-28 Add §7 Layout Design Rationale, fix TOC, update README
    System Design Document:
    - §7 complete (6 subsections): stackup, placement, grounding,
    routing, DFT, manufacturing - all with first-principles derivations
    - Fix §7 TOC to use details/summary collapsible (matches §1-§6)
    - 5 new tables in §7
    - 2826 → 3159 lines
    README.md:
    - SDD stats: 3,100+ lines, 20 figures, 55 tables
    - All SDD sub-items checked complete
    - Add: parameter chain, power/IO specs, filter analysis,
    layout rationale, KiCad SVG integration
    - Remove 'in progress' and 'forthcoming' markers
    - Update Key Documents description with §2.4 and §7
2026-03-29 Restructure SDD to TI datasheet format, update README
    SDD restructured from tutorial-style to TI datasheet conventions:
    1. Features (two-column specs at a glance)
    2. Applications
    3. Description
    4. Functional Block Diagram
    5. Pin Configuration and Functions
    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
2026-03-29 Add schematic and PCB layout change plans to repo
    - Schematic_Updates_Change_Plan.docx: 9 CRs (SCH-00 through SCH-08)
    - PCB_Layout_Change_Plan.docx: 8 tasks (PCB-01 through PCB-08)
    - Fixes broken links in README.md
    - Force-added: *.docx is in .gitignore
2026-06-17 Resolve D5 (calibrated DAC ramp); link SDD in README

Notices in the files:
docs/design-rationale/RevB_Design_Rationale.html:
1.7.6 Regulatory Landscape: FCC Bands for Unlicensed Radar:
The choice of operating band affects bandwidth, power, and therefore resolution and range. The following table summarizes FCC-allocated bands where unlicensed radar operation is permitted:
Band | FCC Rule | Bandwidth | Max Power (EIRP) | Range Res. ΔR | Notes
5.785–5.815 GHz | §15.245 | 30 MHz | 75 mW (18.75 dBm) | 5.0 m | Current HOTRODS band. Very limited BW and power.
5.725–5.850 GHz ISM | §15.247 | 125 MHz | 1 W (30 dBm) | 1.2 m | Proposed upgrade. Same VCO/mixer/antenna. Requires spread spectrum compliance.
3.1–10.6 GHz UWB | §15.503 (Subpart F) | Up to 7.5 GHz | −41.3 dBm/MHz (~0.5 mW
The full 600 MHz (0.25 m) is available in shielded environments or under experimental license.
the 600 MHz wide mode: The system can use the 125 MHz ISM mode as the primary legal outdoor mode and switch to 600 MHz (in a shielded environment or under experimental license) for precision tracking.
